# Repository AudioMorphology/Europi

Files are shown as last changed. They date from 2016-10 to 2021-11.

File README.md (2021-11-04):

# Europi

## Overview

The Europi is a 16hp Eurorack format sequencer powered by the Raspberry Pi single board computer. It is a digital sequencer that outputs Control Voltages (CV), Modulation and Gate signals, and can be controlled by a variety of signal sources including its own internal clock, external clocks, rotary encoders, MIDI sources and the like.

Europi has been designed to be modular and expandable. The main Europi module, which interfaces directly with the Raspberry Pi has the following features:

* 320 x 240 pixel 16-bit colour touchscreen display
* Continuous rotary push-button encoder
* 4 x tactile 'soft' buttons
* 2 x 1 v/Oct CV output (16-Bit resolution over a 10 volt range)
* 2 x Modulation outputs (16-Bit resolution over a 10 volt range)
* 2 x Gate ouputs (+5 volt leading-edge triggered)
* Clock Out
* Clock In
* Step 1 Out
* Reset In
* Hold In

The primary Europi module interfaces with a number of secondary modules.

The 6hp Europi Minion extends the output capabilities of the Europi by providing an additional 4 x CV and 4 x Gate outputs. Up to 8 Minions can be daisy-chained together so that, including the main Europi module, a complete system can support 34 x CV and 34 x Gate outputs.

The Europi MIDI Minion adds MIDI In, Out and Thru capability and can be used as a means of note entry, as a Clock source and also as a MIDI output. Up to 8 MIDI Minions can be connected to a Europi.

The intention is that, being open sourced, the initial hardware platform could be extended to include support for additional modules, control surfaces and such like, either by using the existing I2C bus that links the Europi to the Minions, or leveraging the USB capabilities of the Raspberry Pi.

## Open Source Hardware Certification

Europi Hardware is certified under the Open Source Hardware Certification Program. Certification Number UK000002

## Interfaces

The Europi is not an analogue sequencer, it is a digital sequencer that outputs analogue CV, Mod and Gate signals. Due to its digital nature the CV outputs are not infinitely variable, but are converted from digital to analogue using 16-Bit Digital to Analogue Converters  (DACs). This gives a resolution of around 6,000 discrete steps per octave over a 10 volt range, ie 500 per semitone. So, whilst the CV outputs are not continuously variable as in a true Analogue sequencer, the resolution is sufficiently high such that the difference isn't discernable in the vast majority of applications.

The output of the DACs have a full-scale output range of 0 to approx 5 volts. In reality, due to manufacturing tolerances, these outputs rarely reach a true zero and often have a minimum achievable output of around 20mv, so the DAC outputs are buffered via Op Amps that are biased with a slight negative voltage, and have an amplification factor of around 2.5 thus a true zero and full-scale 10v output can be set in software, which removes the need for complex and fiddly trimmer potentiometers.

The resistors biasing this output buffer circuit could be selected so that the output swings between, say +/-5v instead of the usual 0-10v, which would then be suitable for use as an audio output (via suitable drivers).

The CV and Gate outputs are connected to the Raspberry Pi using the main user Inter-Integrated Circuit (I2C) bus. The Raspberry Pi actually has two I2C busses, though the first (I2C-0) is generally reserved for querying 'hats' - add-on boards that sit on top of the Pi. The I2C bus is the slower of the Pi's two busses, but is the more flexible and extensible of the two. The faster SPI bus is used for the LCD display and its associated touchscreen interface. 

It is the I2C bus that is used to daisy-chain the various Minions to the main Europi. The I2C Bus is driven at 400KHz

The soft buttons, push-button rotary encoder, and external clock and reset inputs are connected to GPIO pins of the Raspberry Pi via suitable interface circuitry which provides over- and reverse-voltage protection.

Future expansion plans include a CV & Gate Input Minion for driving the Europi from External CV/Gate sources, a gesture-based controller, and a USB & HDMI Minion that connects the Raspberry Pi's USB output to a 2-Port Powered USB Hub, and brings the HDMI output through to a Eurorack panel. The latter is intended to make it simpler to pogram the Europi in situ, and opens the possibility for the connection of other control surfaces via USB.  

## Language and environment

Europi is written in C as it is fairly efficient and links directly with the PIGPIO library (see below). System and operational states are held in global variables. Opinions are divided over the use of global variables in C, though our view is that in a monolithic application such as this, global variables are both quick & efficient (less stack overheads) and simple to understand.

The GUI has been developed using Raylib (http://www.raylib.com), a free Open Source graphics library.

Touchscreen Input is interpreted by RayLib and mapped to Mouse Movements using the ts_uinput daemon, part of TSLIB.

## Principle of operation

Europi makes extensive use of the excellent PIGPIO library (https://github.com/joan2937/pigpio), in particular the I2C functions, PWM functions, and alert functions.

The main Internal clock is generated by establishing a PWM output on GPIO pin 18 (physical pin 12) against which a Callback function is registered. This callback function is therefore called each time the PWM output changes state. An internal counter divides this clock by 96 to give an internal resolution of 96 pulses per quarter note PPQN.

Due to the nature of the PIGPIO library, the PWM frequency can only be set to an integer number of cycles per second (Hz) and given the internal 96PPQN division, a range of typical BPM frequencies can be obtained using the following formula: BPM = (PWM/48)/60. So, for example, a PWM frequency of 200Hz will yield a corresponding BPM of 250 201Hz will yield 251.25 Etc. Obviously therefore, some BPM values cannot be realised using the internal clock due to this integer Hz limitation.

Using the external clock is a different matter as, presumably, an external oscillator can be set to any fractional frequency. The external clock is treated similarly to the internal clock - an alert function is registered against the GPIO pin to which it is applied (GPIO pin 12 Physical pin 32) and this is therefore called each time the external clock changes state. 

The MIDI Minion can alo be used as a clock source at the normal speed of 24 PPQN. 

Within the main body of the code, various control flags and counters are used to record the current operational state, internal vs external clock etc.

The main sequencer object is held in a single global structure called, understandably enough, Europi. Yes, this structure is inefficient. Yes, it would have saved space to malloc structures on the fly at startup, but  statically-defined structure such as this is easy to understand, and memory is not particularly at a premium in the Raspberry Pi.

The GUI has been developed using the Raylib graphics library (http://www.raylib.com). This was originally developed for games programming, but its 2D and text-handling elements are ideally suited to simple GUI development.

Although the Raspberry Pi can be configured to expose a TFT screen as a secondary framebuffer, it doesn't support hardware graphics acceleration when writing to it. I therefore chose to use Raylib to write to the default framebuffer /dev/fb0 and to use the free open source utility raspbi2fb (https://github.com/AndrewFromMelbourne/raspi2fb) to mirror /dev/fb0 to /dev/fb1 as this actually gives better graphic performance than writing directly to /dev/fb1

## Setup and Configuration

As always with Eurorack modules, care must be taken when attaching the module to a Eurorack PSU. We have included reverse-protection diodes to protect against inadvertent reversal of the supply connector, and also +12v and -12v marks are included on the silk screen to try and prevent errors. We have adopted the Doepfer 'standard' keyed shrouded header type of connector to also minimise potential errors.

Up to 8 Minions can be daisy-chained to a single Europi. There are two 6-way Minion connection headers on the main Europi board, one each side to make it easier to place the Minions to the left or right (or both) of the main Europi module. Minions can be daisy-chained in any order, the only stipulation being that each must be given a unique address on the I2C bus. Failure to do so will lead to unpredictable results.

The minion header mirrors the first 8 pins of the Raspberry Pi, so Minions can be connected using straight-through 8-way ribbon cables. Care must be taken to make sure Pin 1 is connected to Pin 1 etc.

As the Minion header mirrors the first 8 pins of the Raspberry Pi header, Minions can be connected directly to a Raspberry Pi without the need to include a Europi module, though obviously all of the functionality of the Europi would be missing from such a configuration (touchscreen LCD, rotary encoder etc) though it does represent a cheaper and simpler entry route into the realm of the Europi.

The Minion address is set using a 3-way DIP switch, using standard binary addressing: 000, 001, 010 .... 111 The address is read by the Minion when power is applied, so a Minion's address should never be changed whilst power is connected.

The MIDI Minion uses 2 separate jumpers to set one of 4 possible addresses, so 4 MIDI Minions can be connected to a Europi.

During startup, the Europi will scan the I2C bus looking for attached Minions, and will assign blocks of 4 Tracks to each Minion as it finds them. I2C address scanning starts from 000 so the Minion with the lowest address will be found first, and the highest last. Minion addresses do not have to be consecutive, just unique.

For ease of use, it would seem to make sense to assign Minion addresses in ascending order from left to right, though it's entirely up to you. During startup, the Europi will briefly flash all the Gate LEDs in the order it found them, which provides a useful indicator as to whether all Minions are in the correct order.

The second stage of the configuration is to set the Zero and Full scale levels for each CV output (both Europi and Minions). This only ever needs to be carried out once, or if the number or order of Minions is changed.

## Pi Configuration and Build Notes

These have been moved to the Wiki

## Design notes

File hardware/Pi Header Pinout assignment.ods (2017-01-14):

Europi – Pi Header pin assignments & function
Function | GPIO | Header Pin |  | GPIO | Function | Key
3v3+ | 3v3 | 1 | 2 | +5v | +5v |  | +5v
I2C1 SDA | I2C1 SDA | 3 | 4 | +5v | +5v |  | 3v3
I2C1 SCL | I2C1 SCL | 5 | 6 | GND | GND |  | GND
Enc A | GPIO 4 | 7 | 8 | GPIO 14 | Enc B |  | Input
GND | GND | 9 | 10 | GPIO 15 | Enc Button |  | Output
Touch Interrupt | GPIO 17 | 11 | 12 | GPIO 18 | System Clock |  | SPI Bus
TFT Reset | GPIO 27 | 13 | 14 | GND | GND |  | I2C Bus
TFT DS | GPIO 22 | 15 | 16 | GPIO 23
3v3+ | 3v3 | 17 | 18 | GPIO 24
SPI Input | SPI MOSI | 19 | 20 | GND | GND
SPI Output | SPI MOSO | 21 | 22 | GPIO 25
SPI Clock | SPI CLK | 23 | 24 | SPI CE0 | LCD Chip Select
GND | GND | 25 | 26 | SPI CE1 | Touch Panel Chip Select
I2C0 SDA | I2C0 SDA | 27 | 28 | I2C0 SCL | I2C0 SCL
Button 1 | GPIO 5 | 29 | 30 | GND | GND
Button 2 | GPIO 6 | 31 | 32 | GPIO 12 | CLK In
Button 3 | GPIO 13 | 33 | 34 | GND | GND
Button 4 | GPIO 19 | 35 | 36 | GPIO 16 | Reset In
Run/Stop | GPIO 26 | 37 | 38 | GPIO 20 | Int / Ext
GND | GND | 39 | 40 | GPIO 21 | Poss Button 5??

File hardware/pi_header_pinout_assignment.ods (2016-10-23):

Europi – Pi Header pin assignments & function
Function | GPIO | Header Pin |  | GPIO | Function | Key
3v3+ | 3v3 | 1 | 2 | +5v | +5v |  | +5v
I2C SPA | I2C SPA | 3 | 4 | +5v | +5v |  | 3v3
I2C SCL | I2C SCL | 5 | 6 | GND | GND |  | GND
Enc A | GPIO 4 | 7 | 8 | GPIO 14 | Enc B |  | Input
GND | GND | 9 | 10 | GPIO 15 | Enc Button |  | Output
Touch Interrupt | GPIO 17 | 11 | 12 | GPIO 18 | System Clock |  | SPI Bus
TFT Reset | GPIO 27 | 13 | 14 | GND | GND |  | I2C Bus
TFT DS | GPIO 22 | 15 | 16 | GPIO 23 | n/c |  | Reserved (Pi Hat EEPROM)
3v3+ | 3v3 | 17 | 18 | GPIO 24 | n/c |  | Not Connected
SPI Input | SPI MOSI | 19 | 20 | GND | GND
SPI Output | SPI MOSO | 21 | 22 | GPIO 25 | n/c
SPI Clock | SPI CLK | 23 | 24 | SPI CE0 | LCD Chip Select
GND | GND | 25 | 26 | SPI CE1 | Touch Panel Chip Select
n/c | x | 27 | 28 | x | n/c
Button 1 | GPIO 5 | 29 | 30 | GND | GND
Button 2 | GPIO 6 | 31 | 32 | GPIO 12 | CLK In
Button 3 | GPIO 13 | 33 | 34 | GND | GND
Button 4 | GPIO 19 | 35 | 36 | GPIO 16 | Reset In
Run/Stop | GPIO 26 | 37 | 38 | GPIO 20 | Int / Ext
GND | GND | 39 | 40 | GPIO 21 | n/c

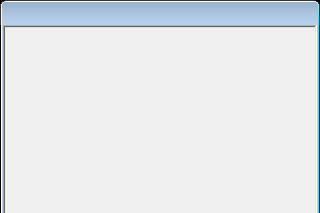
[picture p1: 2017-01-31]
resources/images/dialog.png

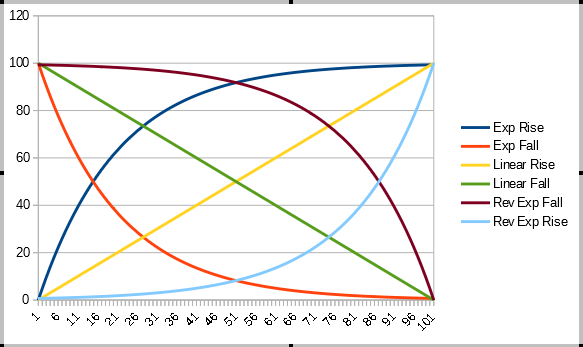
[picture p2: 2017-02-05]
resources/images/slew_profiles.png

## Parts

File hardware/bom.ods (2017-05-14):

Europi & Minion Bill Of Materials
Farnell # | Mouser # | Mfct Part # | Sort | Value | Type | Hole / Package | Europi | Minion | MIDI Minion | Approx Price (£) | Notes
9342400 |  | MF12 1K | 1 | 1k | 125mW 1% through-hole | 5mm | 6 | 4 |  | 0.0556 | Min Qty 5+
9342834 |  | MF12 2K2 | 1 | 2k2 | 125mW 1% through-hole | 5mm | 2 | 4 |  | 0.0526 | Min Qty 5+
9342419 |  | MF12 10K | 1 | 10k | 125mW 1% through-hole | 5mm | 8 | 11 |  | 0.0522 | Min Qty 5
9342826 |  | MF12 220R | 1 | 220R | 125mW 1% through-hole | 5mm | 6 | 8 |  | 0.53 | Sold in multiples of 50
9343245 |  | MF12 470R | 1 | 470R | 125mW 1% through-hole | 5mm | 4 | 4 |  | 0.53 | Sold in multiples of 50
9342800 |  | MF12 200K | 1 | 200k | 125mW 1% through-hole | 5mm | 2 | 4 |  | 0.53 | Sold in multiples of 50
9342850 |  | MF12 220K | 1 | 220k | 125mW 1% through-hole | 5mm |  | 4 |  | 0.53 | Sold in multiples of 50
1700284 |  | MCRE000080 | 1 | 3.9M | 125mW 5% through-hole | 5mm | 2 | 0 |  | 0.0424 | Min Qty 5
2309024 |  | MC0805Y103M500A5.08MM | 2 | 10nF (0.01uF) | Radial Lead ceramic capacitor | 5.08mm | 5 | 7 |  | 0.0934
1216440 |  | MCRR50104X7RK0050 | 2 | 100nF (0.1uF) | Radial Lead ceramic capacitor | 5.08mm | 2 | 2 |  | 0.157 | Min Qty 5
2309021 | 810-FK24X7R1H334K | MC0805B334K500A5.08MM | 2 | 330nF (0.33uF) | Radial Lead ceramic capacitor | 5.08mm | 1 | 1 |  | 0.21
8766754 | 667-EEA-FC1E100 | ECA1EAK100X | 2 | 10uF | Electrolytic 4x7mm 25v | 2.0mm | 3 | 3 |  | 0.0471 | Min Qty 5
9565124 | 512-1N4148 | 1N4148 | 3 | 1N4148 | High speed small signal diode | DO35-7 / 7mm | 8 | 4 |  | 0.0143 | Min Qty 10+
1017589 | 863-1N5819G | 1N5819 | 3 | 1N5819 | Schottky Diode 1A | DO41-7.6 / 7.6mm | 2 | 2 |  | 0.214 | Min Qty 5+
2296047 | 512-LM7805ACT | LM7805ACT | 4 | LM7805 | 5v Regulator | TO-220 | 1 | 1 |  | 0.463 | These are 5v 1A.
 | 511-LD1117S33 | LD1117S33TR | 4 | LD1117 | 3v3 Regulator | SOT-223 | 0 | 0 | 1 | 0.35
1648707 | 595-OPA4130UA | OPA4130UA | 4 | OPA4130 | Quad Op Amp | SOIC-14 | 0 | 1 |  | 5.57
1459554 | 595-OPA2130UA | OPA2130UA | 4 | OPA2130 | Dual Op Amp | SOIC-8 | 1 | 0 |  | 4.04
1206884 | 595-DAC8574IPW | DAC8574IPWG4 | 4 | DAC8574 | Quad 16-Bit DAC | TSSOP-16 | 1 | 1 |  | 13.38
9845330 | 512-BSS138 | BSS138 | 4 | BSS138 | N-Channel MOSFET | SOT-23 | 2 | 2 |  | 0.096 | Min Qty 10+
1332086 |  | MCP23008-E/SO | 4 | MCP23008 | 8-Bit i2c GPIO Extender | SOIC-18 | 0 | 1 |  | 0.818
2101302 |  | PCF8574AT | 4 | PCF8574A | 8-Bit i2c GPIO Extender | SOIC-16 | 1 | 0 |  | 0.765 | Note: 8574A NOT 8574!! This is because it's on a different i2c address that doesn't conflict with MCP23008
 |  | 74HCT125D | 4 |  |  |  |  |  |  |  | Note: MUST be 74HCT not 74HC (ie must work with TTL not CMOS levels)
2402409 |  | 430186130716 | 6 | Momentary | Tall tactile Switch | 4-Pin DIP 7.62x10.16 | 4 | 0 |  | 0.468 | Shaft needs to be >7mm long
2292959 |  | A101CYCQ04 | 6 | SPDT on-on | On-on toggle switch | 4.76mm (3/16”) | 2 | 0 |  | 1.96
2474844 |  | PEC11R-4215F-S0024 | 6 | 2-Channel | 24-Pulse Rotary Encoder | 15mm Shaft length | 1 | 0 |  | 1.31
9473041 |  | 2MS1T1B5M2RE | 6 | On-on Toggle | Through-hole SPDT switch | 6mm | 2 | 0 |  | 1.31
1523985 |  | MCEI-03 | 7 | 3 Circuit Switch | SPST 3 Circuit DIP Switch | 2.54 pitch x 7.62mm | 0 | 1 |  | 0.459
1142502 |  | L-934GD | 3 | Green | 3mm LED | T1 2.54 pitch | 4 | 4 | 2 | 0.082 | Min Qty 5
 |  | PJ301M-12 | 7 | 3.5mm jack Socket | Thonkiconn | 3.5mm | 8 | 8 |  | 0.39 | Buy from Thonk
 |  |  | 7 | Nuts | Hex nuts for Thonkiconn sockets | m6 | 8 | 8 |  | 1.5 | Bag of 50
 | 490-SDS-50J | SDS-50J | 7 | 5-Pin 180 deg | PCB monted right-angle MIDI DIN |  | 0 | 0 | 3 | 0.82 | The ones from Mouser have the mounting holes, which are preferred
1022253 |  | M20-9990546 | 5 |  | 5-Pin DIL Male Header |  | 0 | 1 |  | 0.089 | Min Qty 10+
1593461 |  | 2212S-05SG-85 | 5 |  | 5-Pin DIL Female Header |  | 0 | 1 |  | 0.599 | Min Qty 10+
1022256 |  | M20-9990845 | 5 |  | 8-Pin DIL Male Header |  | 3 | 1 |  | 0.156 | Min Qty 10+
3419101 |  | 215297-8 | 5 |  | 8-Pin DIL Female Header |  | 3 | 0 |  |  | Note: Europi ones need to be low-ish profile (AMP from TE Connectivity from Farnell looks OK)
1593463 |  | 2212S-08SG-85 | 5 |  | 8-Pin DIL Female Header |  | 0 | 1 |  | 0.721 | Needs to match the height of the 5-Pin ones.
2215302 |  | T821106A1S100CEU | 5 |  | 6-Pin Male Shrouded Header |  | 2 | 2 | 2 | 0.47 | each
1392408 |  | 70246-1044 | 5 |  | 10-Pin Male Shrouded Header |  | 1 | 1 |  | 0.782 | Min Qty 5+
 |  |  | 5 |  | 26-Pin Male Header |  | 1 | 0 | 1 |  | For connecting the TFT LCD Screen – 2 x Rows of single pins will do.
2396214 |  | 10-98-7402 | 5 |  | 40-Pin male Header |  | 1 | 0 |  | 2.19 | For Raspberry Pi Zero, or Ribbon from Pi
 |  |  | 8 |  | Rotary encoder knob |  | 1 | 0 |  | 4.99 | For 5. Bought from led-essential on eBay
 |  |  | 8 |  | Eurorack power cable |  | 1 | 1 |  |  | 16pin to 10pin ribbon
 |  |  | 8 |  | Minion link cable |  | 0 | 1 |  |  | 6pin to 6pin ribbon

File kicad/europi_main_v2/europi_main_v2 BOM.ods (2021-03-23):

Id | Designator | Package | Quantity | Designation | Supplier and ref
1 | C1,C2,C5 | CP_Radial_D5.0mm_P2.00mm | 3 | 10uF
2 | C11,C8,C10,C12,C13,C6,C9 | C_0805_2012Metric_Pad1.15x1.40mm_HandSolder | 7 | 10n
3 | D1,D2 | D_DO-41_SOD81_P10.16mm_Horizontal | 2 | 1N5819
4 | D3,D4,D5,D6 | LED_D3.0mm | 4 | LED
5 | D7,D8,D9,D10,D11,D12,D13,D14,D15,D16 | D_SOD-123 | 10 | 1N4148
6 | Eurorack1 | IDC_Header_Straight_10pins | 1 | CONN_02X05
7 | J1,J2,J3,J4,J5,J6,J7,J8,J16,J14,J13 | Thonkiconn | 11 | Thonkiconn
8 | Pi1 | Raspberry_Pi_Zero_Socketed | 1 | Raspberry Pi
9 | Q1,Q2 | SOT-23 | 2 | BSS138
10 | R1,R2,R3,R4,R5,R6,R8,R12 | R_0805_2012Metric_Pad1.15x1.40mm_HandSolder | 8 | 10k
11 | R17,R18,R19,R20,R27,R28,R40,R39 | R_0805_2012Metric_Pad1.15x1.40mm_HandSolder | 8 | 220R
12 | R21,R22,R23,R24 | R_0805_2012Metric_Pad1.15x1.40mm_HandSolder | 4 | 470R
13 | R25,R26,R41 | R_0805_2012Metric_Pad1.15x1.40mm_HandSolder | 3 | 3m6
14 | R29,R30,R42 | R_0805_2012Metric_Pad1.15x1.40mm_HandSolder | 3 | 1K
15 | SW1 | SPDT_Switch | 1 | SW_SPDT
16 | SW3 | Rotary_encoder_sw_concise | 1 | RotaryEncoder_Switch
17 | SW4 | SW_PUSH_6mm | 1 | BTN_1
18 | SW5 | SW_PUSH_6mm | 1 | BTN_2
19 | SW6 | SW_PUSH_6mm | 1 | BTN_3
20 | SW7 | SW_PUSH_6mm | 1 | BTN_4
21 | PCF8574A1 | SOIC-16W_7.5x10.3mm_P1.27mm | 1 | PCF8574A
22 | , | AM_Logo | 2
23 |  | OSHW-Logo2_14.6x12mm_SilkScreen | 1
24 | R32,R31,R34,R33,R9,R10,R11,R7 | R_0805_2012Metric_Pad1.15x1.40mm_HandSolder | 8 | 1k
25 | R37,R36,R35,R38 | R_0805_2012Metric_Pad1.15x1.40mm_HandSolder | 4 | 2k2
26 | R14,R16,R15,R13 | R_0805_2012Metric_Pad1.15x1.40mm_HandSolder | 4 | 200k
27 | OPA4130 | SOIC-14_3.9x8.7mm_P1.27mm | 1 | OPA4134
28 | C4,C7 | tantalum_capacitor | 2 | 100n
29 | C3 | tantalum_capacitor | 1 | 330n
30 | LM7805 | TO-220-3_Vertical | 1 | LM7805_TO220
31 | J11,J9 | PinHeader_2x04_P2.54mm_Vertical | 2 | Conn_02x04_Odd_Even
32 | DAC8574 | TSSOP-16_4.4x5mm_P0.65mm | 1 | DAC8574
33 | P3,P4,P6,P7 | PinHeader_1x08_P2.54mm_Vertical | 4 | Conn_01x08
34 | J17,J19 | PinHeader_1x06_P2.54mm_Vertical | 2 | Conn_01x06
35 | J18,J20 | PinHeader_1x05_P2.54mm_Vertical | 2 | Conn_01x05
36 | J10 | MSP2402 | 1 | Conn_01x14

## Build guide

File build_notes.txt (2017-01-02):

Europi Install & Build instructions

Download, compile and install the PIGPIO library\	

edit /boot/config.txt and take the comment off the following line:
#dtparam=spi=on

add the following line to prevent the under-voltage warning being displayed if
the power voltage drops:
avoid_warnings=1

Note: If you change the 1 to a 2, then it will also prevent the Pi disabling Turbo mode
if the power drops (normal behaviour). i thought this a bit risky, as it might cause the 
pi to crash, hence why I stuck with the =1

Add the ads7846 touchscreen overlay:
 - Towards the end of /boot/config.txt add the following line:
 dtoverlay=ads7846,penirq=17,speed=1600000,xohms=100

The following line loads the fbtft driver manually, though note that later on in this doc
there is an explanation as to how to load the fbtft driver at boot time

sudo modprobe fbtft_device custom name=fb_iti9340 buswidth=8 speed=16000000 bgr=1 gpios=reset:27,dc:22 rotate=270

Also in /boot/config.txt if you add the following lines, it will force the raspberry Pi into native 
1280x960 graphics mode, which is the same aspect ration (4:3) as the 320x240 TFT display. Doing
this has certain advantages inasmuch as it is then possible, whilst deverloping under X11
to check the resulting display on the 320x240TFT display as it scales exactly:

framebuffer_width=1280
framebuffer_height=960
hdmi_group=2
hdmi_mode=32
hdmi_cvt 1280 960 60 1 0 0 0 

When you are ready to run headless with only the TFT display, use the following instead, which 
will set the Pi to native 320x240:
framebuffer_width=320
framebuffer_height=240
hdmi_group=2
hdmi_mode=87
hdmi_cvt 320 240 60 1 0 0 0 

The following two changes mean that you don't have to run the sudo modprobe line each time the pi boots:

>sudo nano /etc/modules-load.d/modules.conf

add the following 2 lines:

spi-bcm2835
fbtft_device

>sudo nano /etc/modprobe.d/fbtft.conf   (ie create this file, as it probably doesn't already exist)

add the following line:

options fbtft_device custom name=fb_ili9340 buswidth=8 speed=16000000 bgr=1 gpios=reset:27,dc:22 rotate=270

Note that the argument bgr=1 is only necessary to fix the situation where Red and Blue colours are swapped, which
it the case with the SpotPear TFT Screens.

To get europi to run automatically at startup, do the following: 

>sudo crontab -e

If it gives you a choice of editor, choose whichever you want (I use nano). Once you have made a choice, it'll open in that editor from then onwards

Add the following to the bottom of the crontab file:

@reboot /usr/bin/sudo /home/pi/projects/Europi/europi

SET The Touchscreen Device:
Depending on how many devices are connected to the SPI bus, the Touchscreen may appear as
device1, 2,  3 etc., to view the input devices:
>cat /proc/bus/input/devices

Mine looks like this:
I: Bus=0000 Vendor=0000 Product=0000 Version=0000
N: Name="ADS7846 Touchscreen"
P: Phys=spi0.1/input0
S: Sysfs=/devices/platform/soc/3f204000.spi/spi_master/spi0/spi0.1/input/input3
U: Uniq=
H: Handlers=mouse1 event3 
B: PROP=0
B: EV=b
B: KEY=400 0 0 0 0 0 0 0 0 0 0
B: ABS=1000003

That H: line shows that it is being handled by event3

Fri 24th June: I was adding stuff to get me to the stsage where I could use IOCTL to read touch events
I got the prog to compile OK, but it crashes with a SIGINT 11 (basically a memory violation) as it 
tries to query the device capabilities.

Sat 25th Jun: I removed all the touchscreen code I'd added, and decided instead to just try linking 
in the example C code from Mark Williams

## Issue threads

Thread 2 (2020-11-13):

Continue development?

Deftaudio, 2020-11-13:
Hi, just wondering if you continue developing of this project by adding more features or it's abandoned?

AudioMorphology, 2020-11-13:
Hi, I stopped development as I wasn't happy with the mechanical attachment of the Pi Zero or the computing power of the Pi Zero at that time. I also needed time (and money) to buy more Eurorack modules - a fully-populated EuroPi can drive 30+ CV and Gate outputs, so I needed more modules to control!

However, now that the Pi 4 Compute Module (CM4) has been released I plan to re-design the hardware to use the CM4, I have one on order and I expect it to arrive next week.

The form factor is much better for attaching to the rear of a Eurorack module.

I also realised that, for MIDI in, I really needed to bring an interrupt line from the MIDI Minion, because Polling for MIDI messages gave me lots of timing problems.

So, nothing has happened for a long time, but I hope to be able to start on a new version soon!

Richard

Deftaudio, 2020-11-13:
Hi Richard, this is great to hear. I've been thinking about Pi based design for quite few years. My idea was to use it mainly for MIDI processing within PD. So with that I can't use custom circuit to drive digital pins without actually writing a full MIDI driver stack. So, as I'm not experienced in that,  I've been thinking on the Teensy+Pi design. in the meantime, with all overhead of the polling mode, this is the approach for low jitter implementation, even consuming lot of Pi cycles.

Closed 2021-02-23.

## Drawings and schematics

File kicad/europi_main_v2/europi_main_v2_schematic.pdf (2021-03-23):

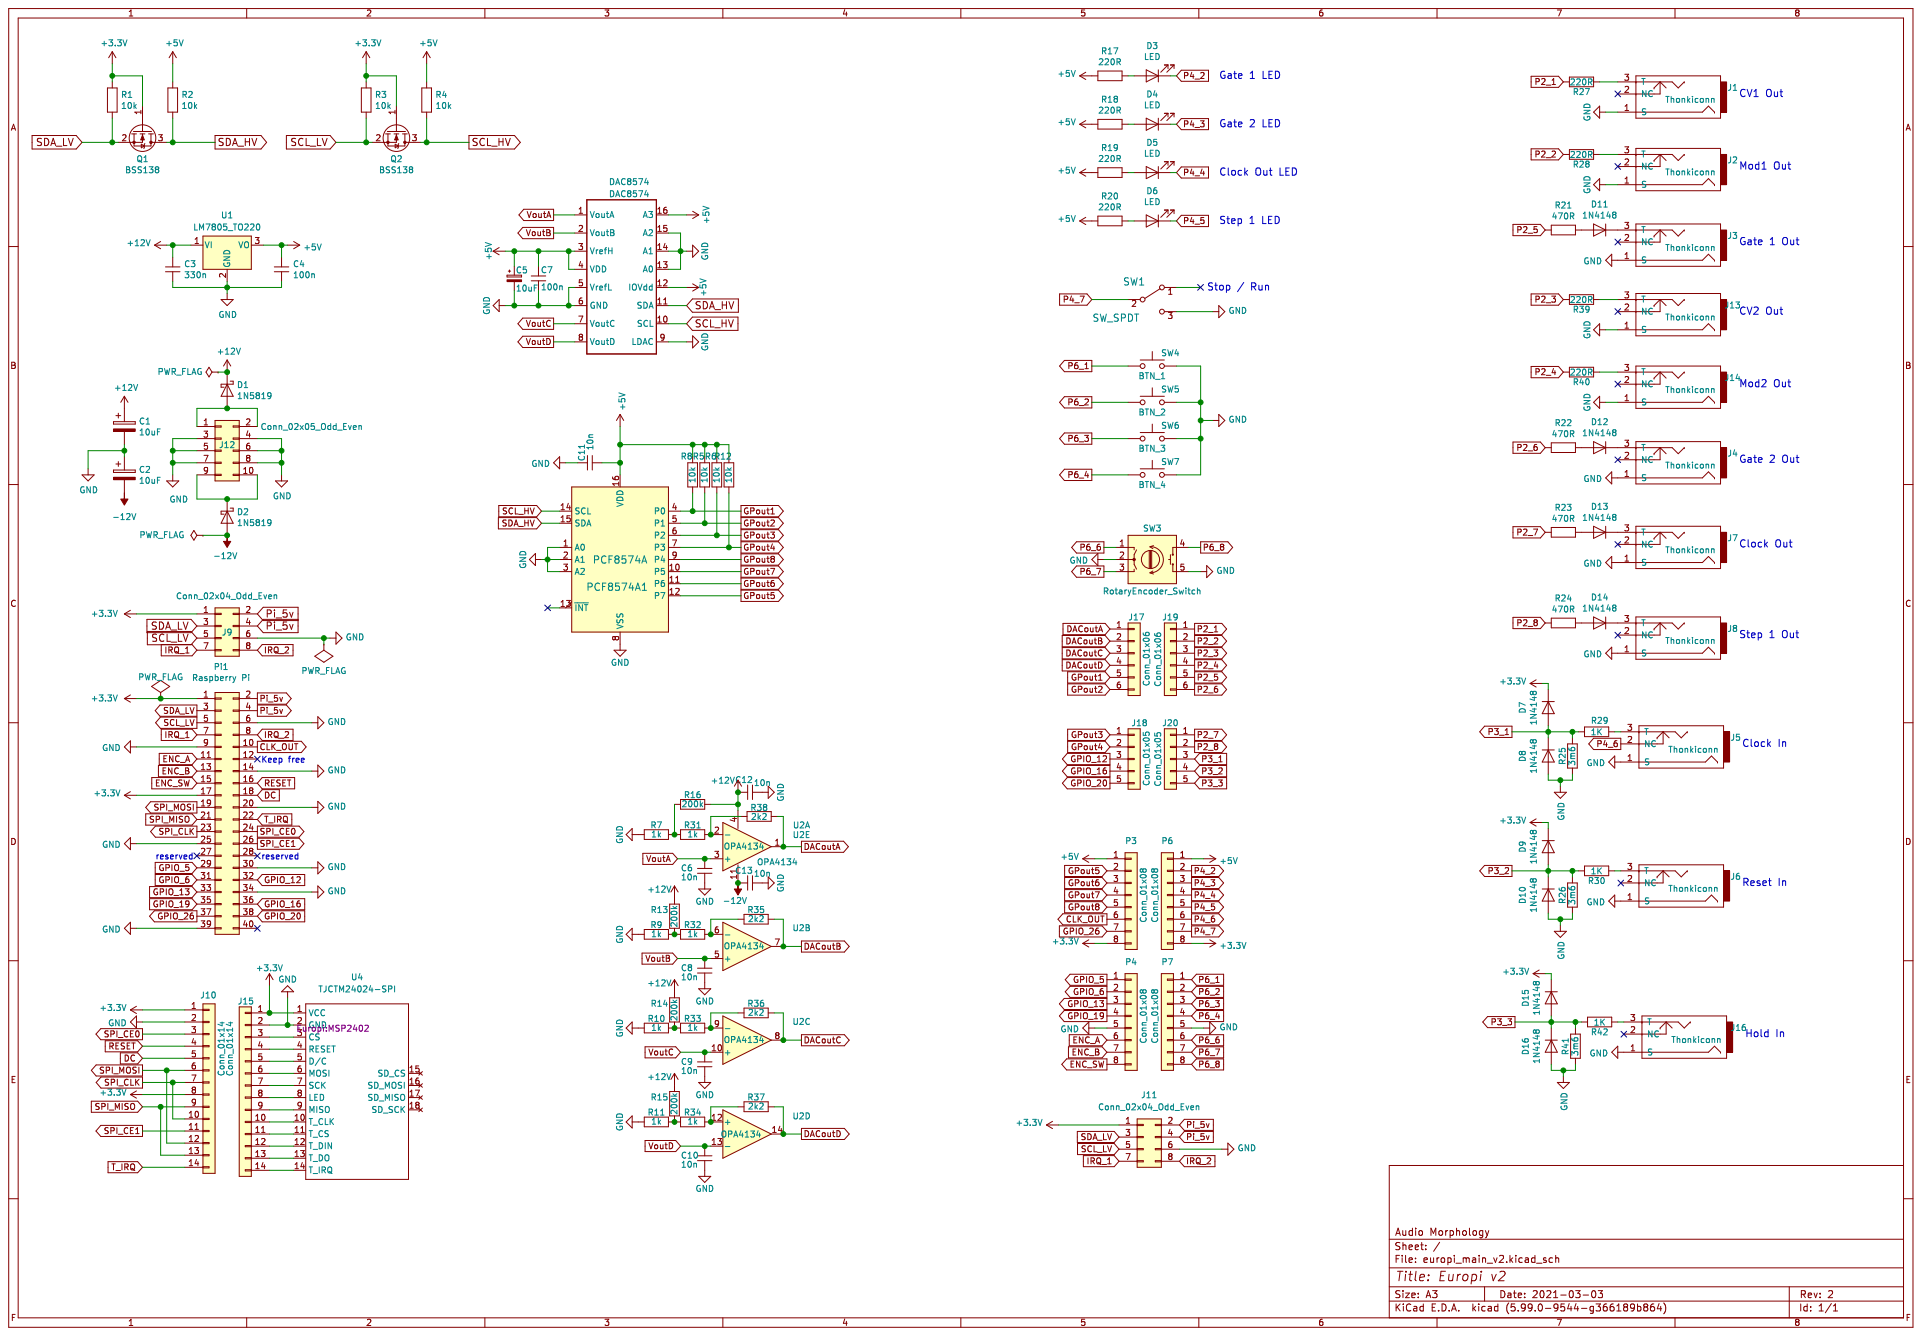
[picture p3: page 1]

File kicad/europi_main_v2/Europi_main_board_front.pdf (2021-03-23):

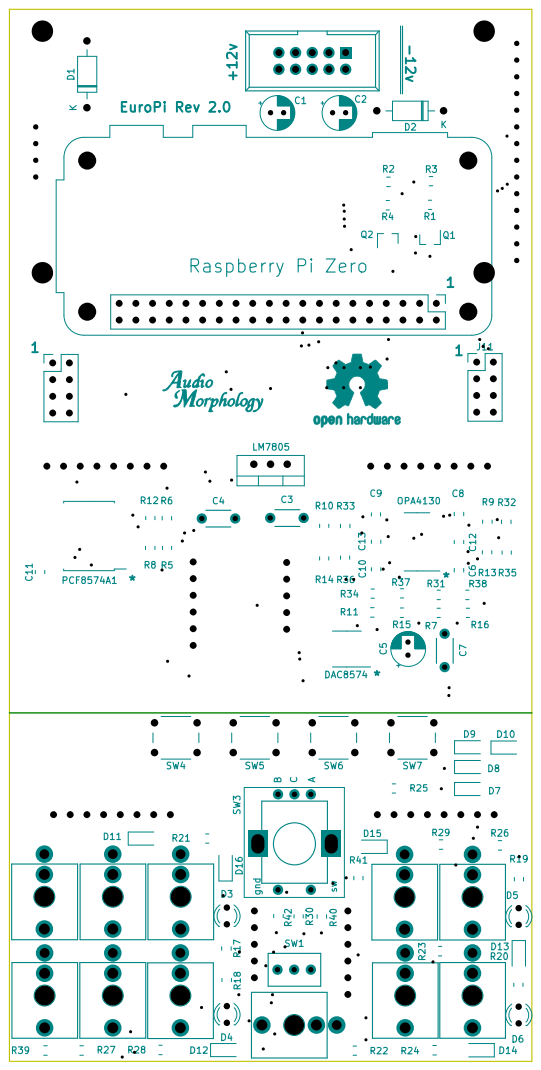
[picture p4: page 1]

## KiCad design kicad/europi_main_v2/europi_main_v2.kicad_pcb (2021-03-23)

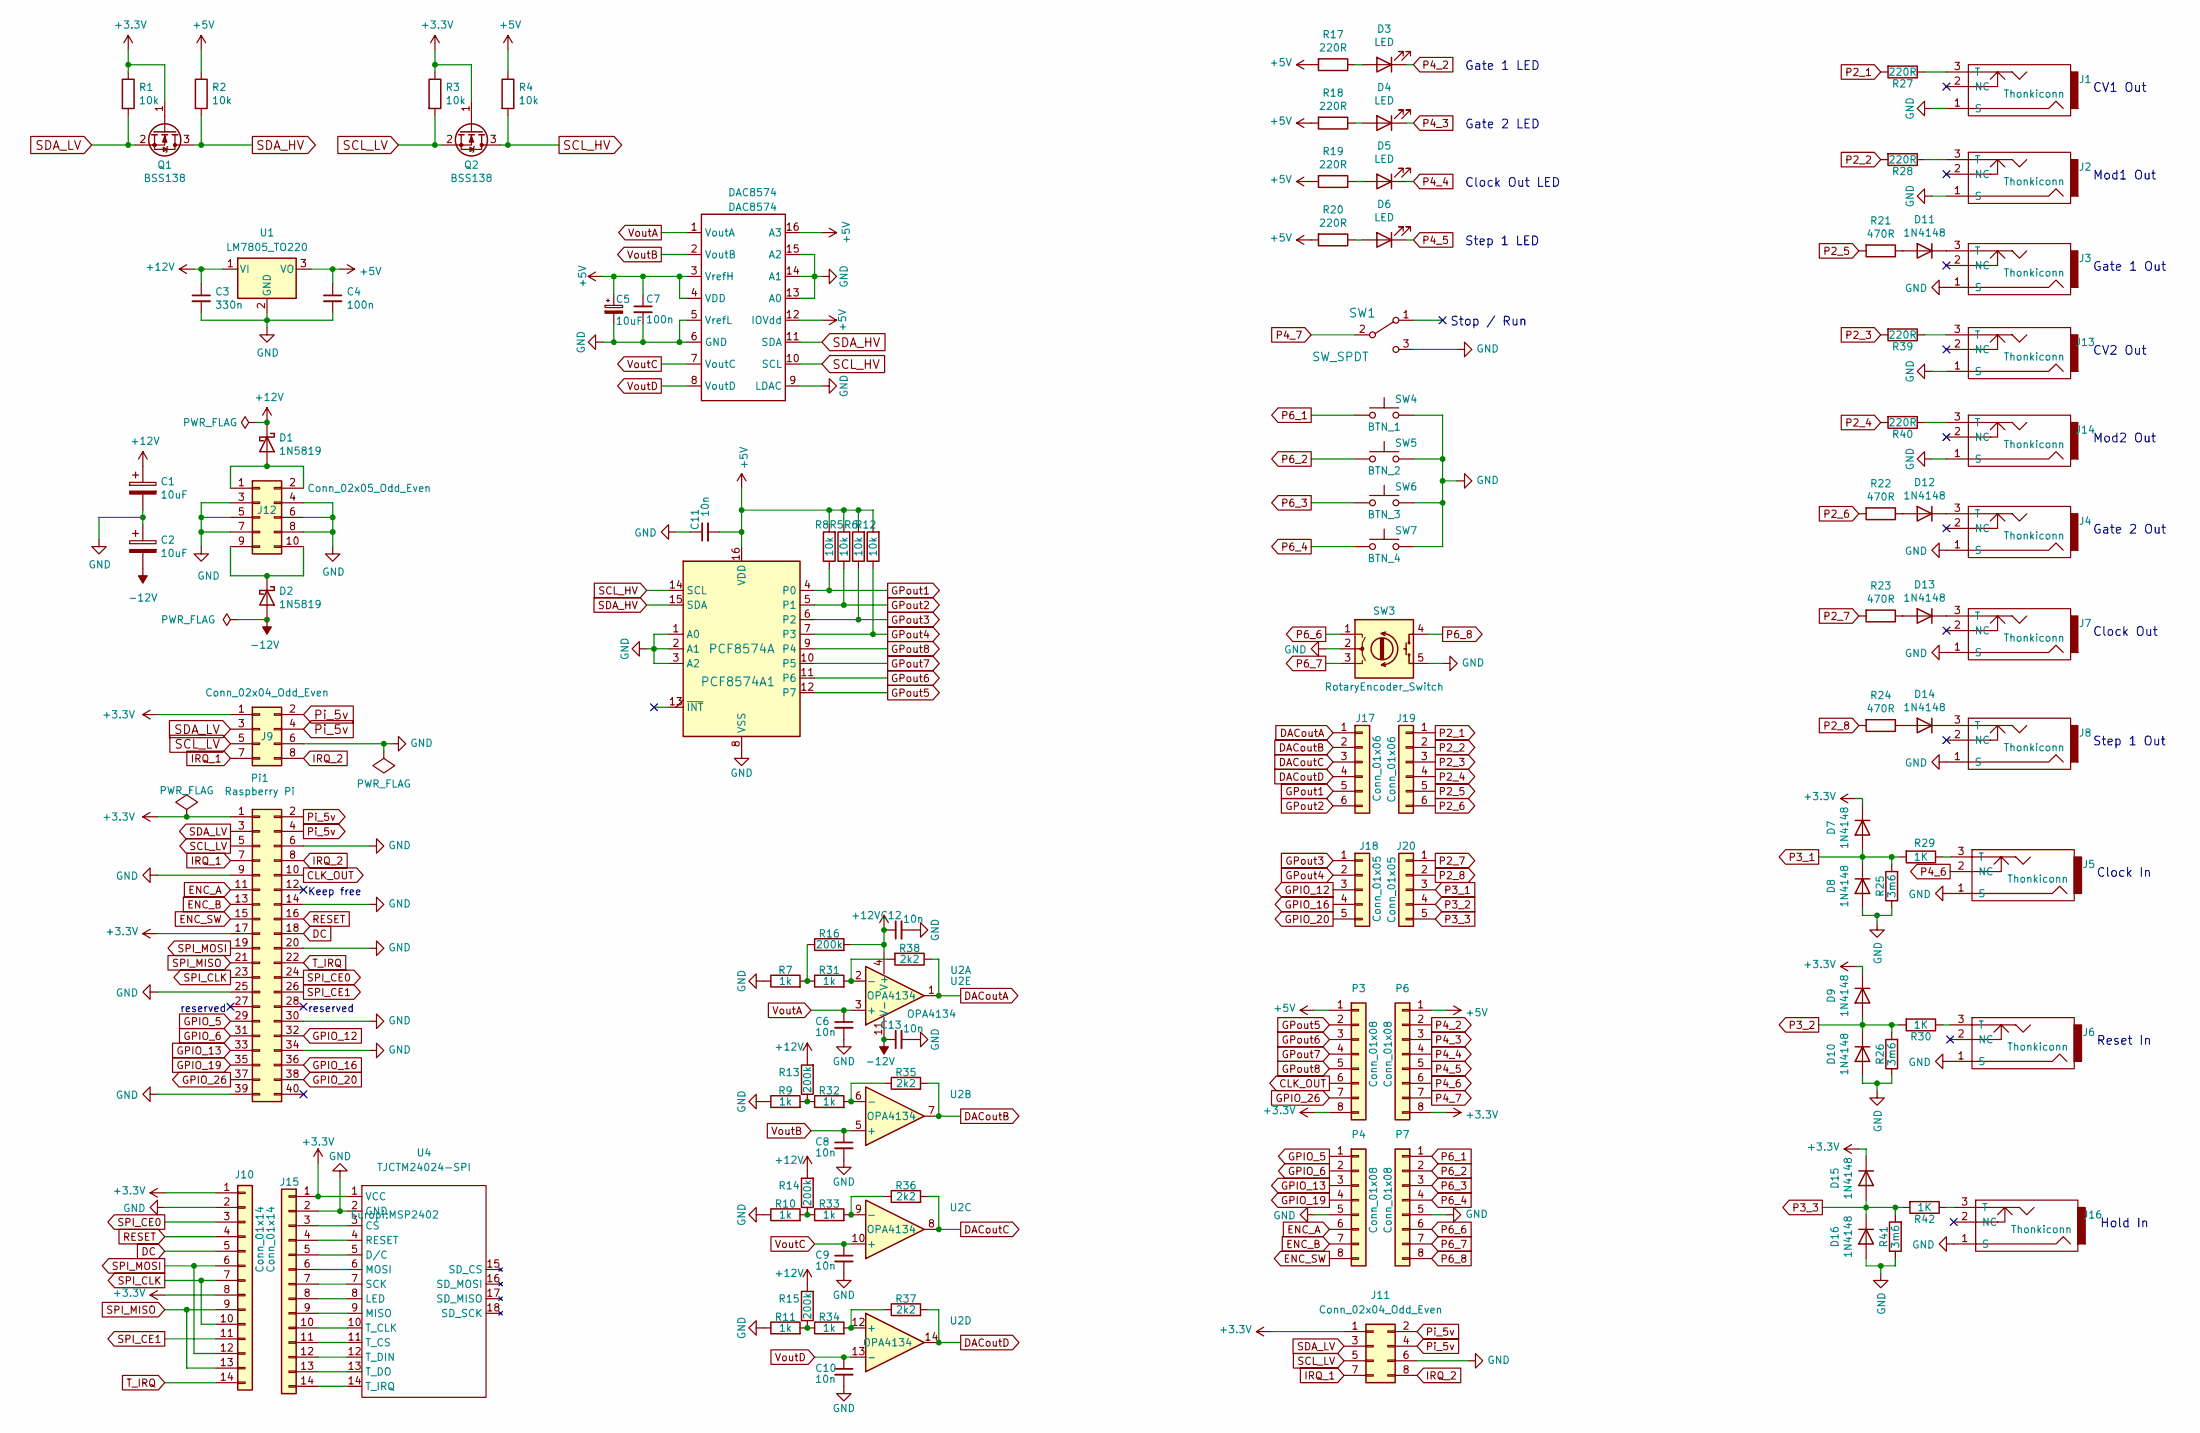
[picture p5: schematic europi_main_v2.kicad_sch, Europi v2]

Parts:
C1, C2, C5: 10uF; CP_Radial_D5.0mm_P2.00mm
C3: 330n; tantalum_capacitor
C4, C7: 100n; tantalum_capacitor
C6, C8, C9, C10, C11, C12, C13: 10n; C_0805_2012Metric_Pad1.15x1.40mm_HandSolder
D1, D2: 1N5819; D_DO-41_SOD81_P10.16mm_Horizontal
D3, D4, D5, D6: LED; LED_D3.0mm
D7, D8, D9, D10, D11, D12, D13, D14, D15, D16: 1N4148; D_SOD-123
DAC8574: DAC8574; TSSOP-16_4.4x5mm_P0.65mm
J1, J2, J3, J4, J5, J6, J7, J8, J13, J14, J16: Thonkiconn
J9, J11: Conn_02x04_Odd_Even; PinHeader_2x04_P2.54mm_Vertical
J10, J15: Conn_01x14; PinHeader_1x14_P2.54mm_Vertical
J12: Conn_02x05_Odd_Even; PinHeader_2x05_P2.54mm_Vertical
J17, J19: Conn_01x06; PinHeader_1x06_P2.54mm_Vertical
J18, J20: Conn_01x05; PinHeader_1x05_P2.54mm_Vertical
P3, P4, P6, P7: Conn_01x08; PinHeader_1x08_P2.54mm_Vertical
PCF8574A1: PCF8574A; SOIC-16W_7.5x10.3mm_P1.27mm
Pi1: Raspberry Pi; Raspberry_Pi_Zero_Socketed
Q1, Q2: BSS138; SOT-23
R1, R2, R3, R4, R5, R6, R8, R12: 10k; R_0805_2012Metric_Pad1.15x1.40mm_HandSolder
R7, R9, R10, R11, R31, R32, R33, R34: 1k; R_0805_2012Metric_Pad1.15x1.40mm_HandSolder
R13, R14, R15, R16: 200k; R_0805_2012Metric_Pad1.15x1.40mm_HandSolder
R17, R18, R19, R20, R27, R28, R39, R40: 220R; R_0805_2012Metric_Pad1.15x1.40mm_HandSolder
R21, R22, R23, R24: 470R; R_0805_2012Metric_Pad1.15x1.40mm_HandSolder
R25, R26, R41: 3m6; R_0805_2012Metric_Pad1.15x1.40mm_HandSolder
R29, R30, R42: 1K; R_0805_2012Metric_Pad1.15x1.40mm_HandSolder
R35, R36, R37, R38: 2k2; R_0805_2012Metric_Pad1.15x1.40mm_HandSolder
SW1: SW_SPDT; SPDT_Switch
SW3: RotaryEncoder_Switch; Rotary_encoder_sw_concise
SW4: BTN_1; SW_PUSH_6mm
SW5: BTN_2; SW_PUSH_6mm
SW6: BTN_3; SW_PUSH_6mm
SW7: BTN_4; SW_PUSH_6mm
U1: LM7805_TO220; TO-220-3_Vertical
U2: OPA4134; SOIC-14_3.9x8.7mm_P1.27mm
U4: TJCTM24024-SPI; MSP2402

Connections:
+3V3: D7.1 (K), D9.1 (K), D15.1 (K), J9.1, J10.1, J10.8, J11.1, J15.1, P3.8, P6.8, Pi1.1, Pi1.17, Q1.1 (G), Q2.1 (G), R1.1, R3.1, U4.1 (VCC)
+5V: C4.1, C5.1, C7.1, C11.2, DAC8574.3 (VrefH), DAC8574.4 (VDD), DAC8574.12 (IOVdd), DAC8574.16 (A3), P3.1, P6.1, PCF8574A1.16 (VDD), R2.1, R4.1, R5.2, R6.2, R8.2, R12.2, R17.2, R18.2, R19.2, R20.2, U1.3 (VO); also elsewhere on the board
+12V: C1.1, C3.1, C12.1, D1.1 (K), R13.2, R14.2, R15.2, R16.2, U1.1 (VI), U2.4 (V+); also elsewhere on the board
-12V: C2.2, C13.1, D2.2 (A), U2.11 (V-); also elsewhere on the board
CLK_OUT: P3.6, Pi1.10
DACoutA: J17.1, R38.1, U2.1; also elsewhere on the board
DACoutB: J17.2, R35.2, U2.7; also elsewhere on the board
DACoutC: J17.3, R36.2, U2.8; also elsewhere on the board
DACoutD: J17.4, R37.2, U2.14; also elsewhere on the board
DC: J10.5, Pi1.18
ENC_A: P4.6, Pi1.11
ENC_B: P4.7, Pi1.13
ENC_SW: P4.8, Pi1.15
GND: C1.2, C2.1, C3.2, C4.2, C5.2, C6.2, C7.2, C8.2, C9.2, C10.2, C11.1, C12.2, C13.2, D8.2 (A), D10.2 (A), D16.2 (A), DAC8574.5 (VrefL), DAC8574.6 (GND), DAC8574.9 (LDAC), DAC8574.13 (A0), DAC8574.14 (A1), DAC8574.15 (A2), J1.1 (S), J2.1 (S), J3.1 (S), J4.1 (S), J5.1 (S), J6.1 (S), J7.1 (S), J8.1 (S), J9.6, J10.2, J11.6, J12.3, J12.4, J12.5, J12.6, J12.7, J12.8, J13.1 (S), J14.1 (S), J15.2, J16.1 (S), P4.5, P7.5, PCF8574A1.1 (A0), PCF8574A1.2 (A1), PCF8574A1.3 (A2), PCF8574A1.8 (VSS), Pi1.6, Pi1.9, Pi1.14, Pi1.20, Pi1.25, Pi1.30, Pi1.34, Pi1.39, R7.1, R9.1, R10.1, R11.1, R25.1, R26.1, R41.1, SW1.3 (C), SW3.2 (C), SW3.5 (S2), SW4.2, SW5.2, SW6.2, SW7.2, U1.2 (GND), U4.2 (GND); also elsewhere on the board
GPIO_5: P4.1, Pi1.29
GPIO_6: P4.2, Pi1.31
GPIO_12: J18.3, Pi1.32
GPIO_13: P4.3, Pi1.33
GPIO_16: J18.4, Pi1.36
GPIO_19: P4.4, Pi1.35
GPIO_20: J18.5, Pi1.38
GPIO_26: P3.7, Pi1.37
GPout1: J17.5, PCF8574A1.4 (P0), R8.1
GPout2: J17.6, PCF8574A1.5 (P1), R5.1
GPout3: J18.1, PCF8574A1.6 (P2), R6.1
GPout4: J18.2, PCF8574A1.7 (P3), R12.1
GPout5: P3.2, PCF8574A1.12 (P7)
GPout6: P3.3, PCF8574A1.11 (P6)
GPout7: P3.4, PCF8574A1.10 (P5)
GPout8: P3.5, PCF8574A1.9 (P4)
IRQ_1: J9.7, J11.7, Pi1.7
IRQ_2: J9.8, J11.8, Pi1.8
unnamed 32: D1.2 (A), J12.1, J12.2; also elsewhere on the board
unnamed 33: D2.1 (K), J12.9, J12.10; also elsewhere on the board
unnamed: D3.2 (A), R17.1
unnamed: D4.2 (A), R18.1
unnamed: D5.2 (A), R19.1
unnamed: D6.2 (A), R20.1
unnamed: D11.1 (K), J3.3 (T)
unnamed: D11.2 (A), R21.1
unnamed: D12.1 (K), J4.3 (T)
unnamed: D12.2 (A), R22.1
unnamed: D13.1 (K), J7.3 (T)
unnamed: D13.2 (A), R23.1
unnamed: D14.1 (K), J8.3 (T)
unnamed: D14.2 (A), R24.1
unnamed: J1.3 (T), R27.1
unnamed: J2.3 (T), R28.1
unnamed: J5.3 (T), R29.1
unnamed: J6.3 (T), R30.1
unnamed: J13.3 (T), R39.1
unnamed: J14.3 (T), R40.1
unnamed: J15.3, U4.3 (CS)
unnamed: J15.4, U4.4 (RESET)
unnamed: J15.5, U4.5 (D/C)
unnamed: J15.6, U4.6 (MOSI)
unnamed: J15.7, U4.7 (SCK)
unnamed: J15.8, U4.8 (LED)
unnamed: J15.9, U4.9 (MISO)
unnamed: J15.10, U4.10 (T_CLK)
unnamed: J15.11, U4.11 (T_CS)
unnamed: J15.12, U4.12 (T_DIN)
unnamed: J15.13, U4.13 (T_DO)
unnamed: J15.14, U4.14 (T_IRQ)
unnamed: J16.3 (T), R42.1
unnamed: R10.2, R14.1, R33.1
unnamed: R11.2, R15.1, R34.1
unnamed: R9.2, R13.1, R32.1
unnamed: R7.2, R16.1, R31.1
unnamed 69: R31.2, R38.2, U2.2 (-); also elsewhere on the board
unnamed 70: R32.2, R35.1, U2.6 (-); also elsewhere on the board
unnamed 71: R33.2, R36.1, U2.9 (-); also elsewhere on the board
unnamed 72: R34.2, R37.1, U2.12 (+); also elsewhere on the board
P2_1: J19.1, R27.2
P2_2: J19.2, R28.2
P2_3: J19.3, R39.2
P2_4: J19.4, R40.2
P2_5: J19.5, R21.2
P2_6: J19.6, R22.2
P2_7: J20.1, R23.2
P2_8: J20.2, R24.2
P3_1: D7.2 (A), D8.1 (K), J20.3, R25.2, R29.2
P3_2: D9.2 (A), D10.1 (K), J20.4, R26.2, R30.2
P3_3: D15.2 (A), D16.1 (K), J20.5, R41.2, R42.2
P4_2: D3.1 (K), P6.2
P4_3: D4.1 (K), P6.3
P4_4: D5.1 (K), P6.4
P4_5: D6.1 (K), P6.5
P4_6: J5.2 (NC), P6.6
P4_7: P6.7, SW1.2 (B)
P6_1: P7.1, SW4.1
P6_2: P7.2, SW5.1
P6_3: P7.3, SW6.1
P6_4: P7.4, SW7.1
P6_6: P7.6, SW3.1 (A)
P6_7: P7.7, SW3.3 (B)
P6_8: P7.8, SW3.4 (S1)
Pi_5v: J9.2, J9.4, J11.2, J11.4, Pi1.2, Pi1.4
RESET: J10.4, Pi1.16
SCL_HV: DAC8574.10 (SCL), PCF8574A1.14 (SCL), Q2.3 (D), R4.2
SCL_LV: J9.5, J11.5, Pi1.5, Q2.2 (S), R3.2
SDA_HV: DAC8574.11 (SDA), PCF8574A1.15 (SDA), Q1.3 (D), R2.2
SDA_LV: J9.3, J11.3, Pi1.3, Q1.2 (S), R1.2
SPI_CE0: J10.3, Pi1.24
SPI_CE1: J10.11, Pi1.26
SPI_CLK: J10.7, J10.10, Pi1.23
SPI_MISO: J10.9, J10.13, Pi1.21
SPI_MOSI: J10.6, J10.12, Pi1.19
T_IRQ: J10.14, Pi1.22
VoutA: C6.1, DAC8574.1 (VoutA), U2.3 (+); also elsewhere on the board
VoutB: C8.1, DAC8574.2 (VoutB), U2.5 (+); also elsewhere on the board
VoutC: C9.1, DAC8574.7 (VoutC), U2.10 (+); also elsewhere on the board
VoutD: C10.1, DAC8574.8 (VoutD), U2.13 (-); also elsewhere on the board

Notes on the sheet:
reserved
Keep free
Stop / Run
Gate 1 LED
Gate 2 LED
Clock Out LED
Step 1 LED
CV1 Out
Mod1 Out
Gate 1 Out
CV2 Out
Mod2 Out
Gate 2 Out
Clock Out
Step 1 Out
Clock In
Reset In
Hold In

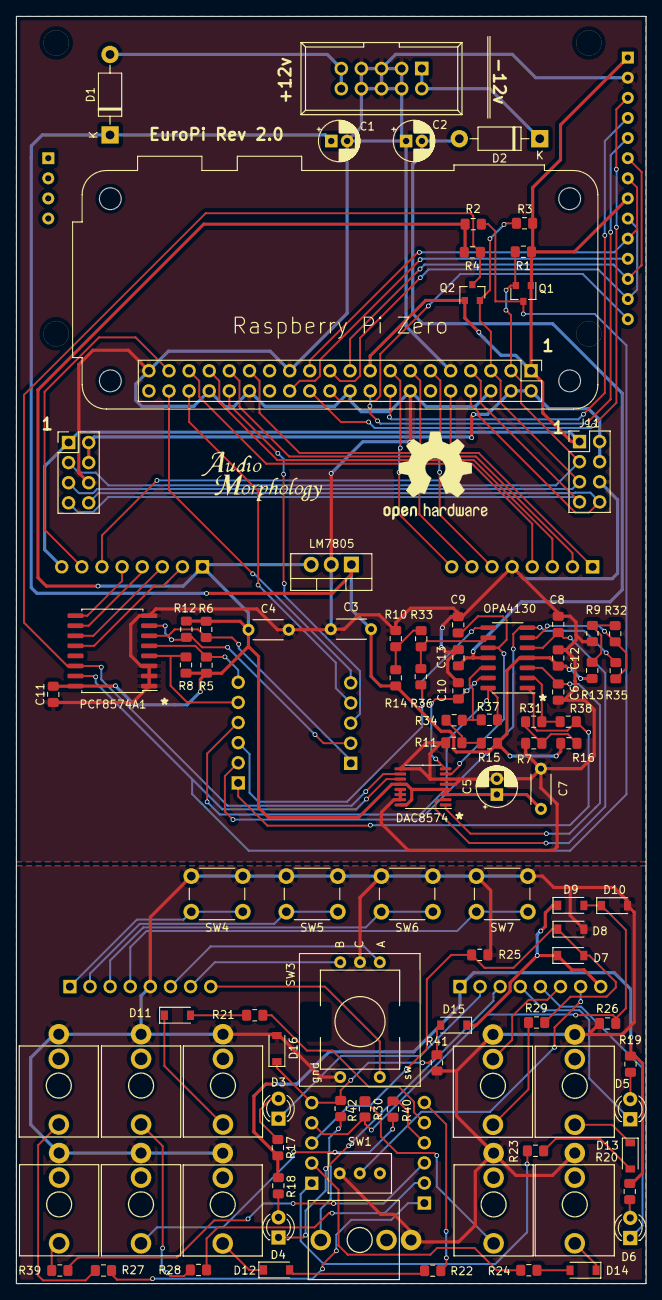
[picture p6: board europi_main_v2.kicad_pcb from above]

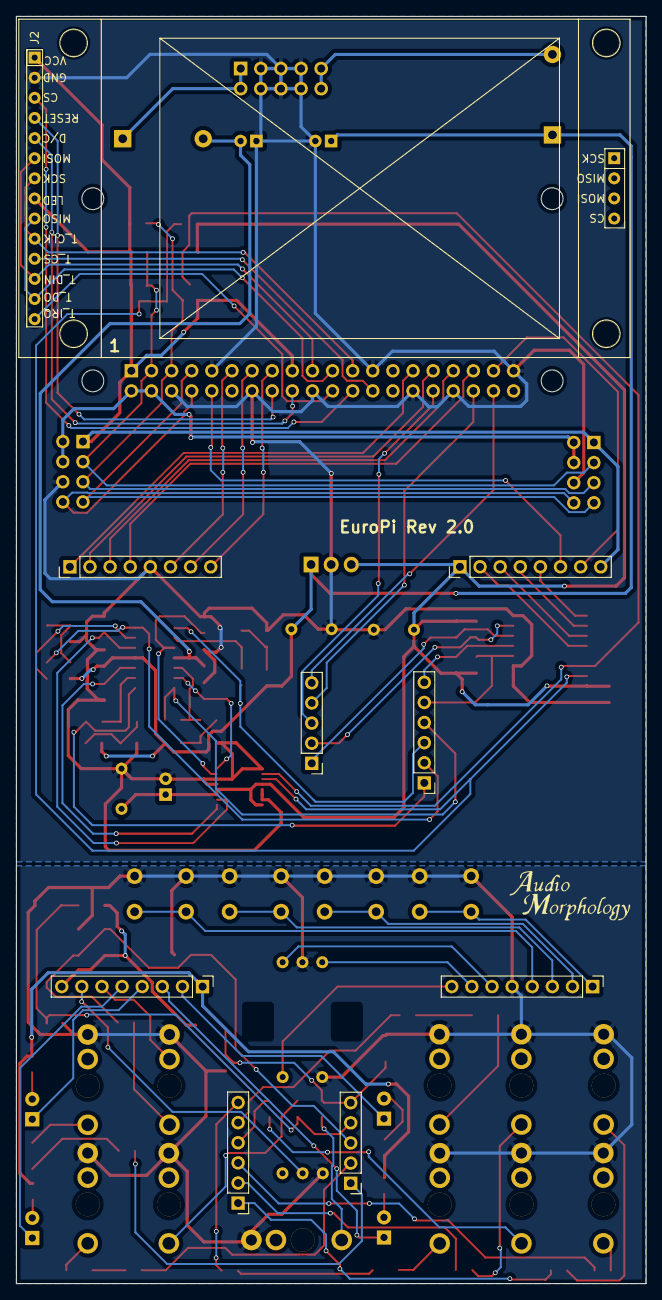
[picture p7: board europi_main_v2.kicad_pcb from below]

Board: 2 copper layers, 79.5 x 160.0 mm, 107 parts (9 on the bottom side), 101 nets.

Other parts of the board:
Eurorack1: CONN_02X05; IDC_Header_Straight_10pins
LM7805: LM7805_TO220; TO-220-3_Vertical
OPA4130: OPA4134; SOIC-14_3.9x8.7mm_P1.27mm

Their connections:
+5V: LM7805.3 (VO); also elsewhere on the board
+12V: LM7805.1 (VI), OPA4130.4 (V+); also elsewhere on the board
-12V: OPA4130.11 (V-); also elsewhere on the board
DACoutA: OPA4130.1; also elsewhere on the board
DACoutB: OPA4130.7; also elsewhere on the board
DACoutC: OPA4130.8; also elsewhere on the board
DACoutD: OPA4130.14; also elsewhere on the board
GND: Eurorack1.3, Eurorack1.4, Eurorack1.5, Eurorack1.6, Eurorack1.7, Eurorack1.8, LM7805.2 (GND); also elsewhere on the board
unnamed 32: Eurorack1.9, Eurorack1.10; also elsewhere on the board
unnamed 33: Eurorack1.1, Eurorack1.2; also elsewhere on the board
unnamed 69: OPA4130.2 (-); also elsewhere on the board
unnamed 70: OPA4130.6 (-); also elsewhere on the board
unnamed 71: OPA4130.9 (-); also elsewhere on the board
unnamed 72: OPA4130.12 (+); also elsewhere on the board
VoutA: OPA4130.3 (+); also elsewhere on the board
VoutB: OPA4130.5 (+); also elsewhere on the board
VoutC: OPA4130.10 (+); also elsewhere on the board
VoutD: OPA4130.13 (-); also elsewhere on the board

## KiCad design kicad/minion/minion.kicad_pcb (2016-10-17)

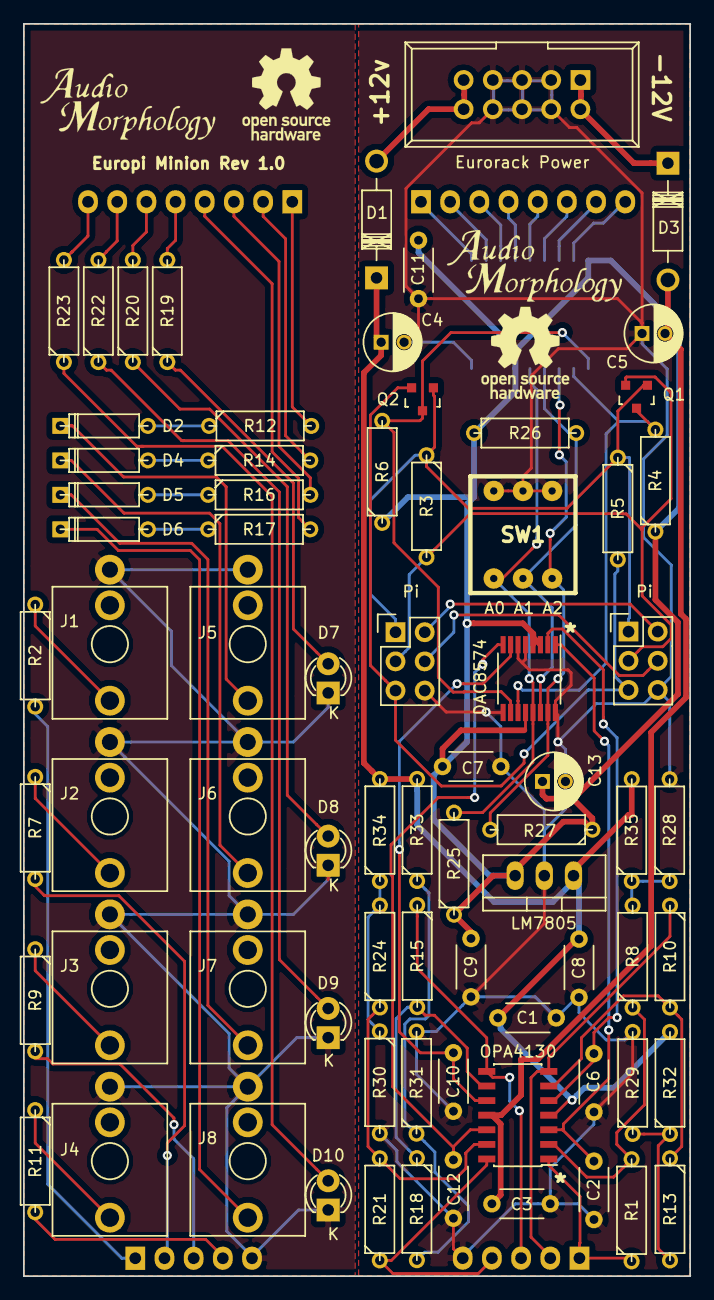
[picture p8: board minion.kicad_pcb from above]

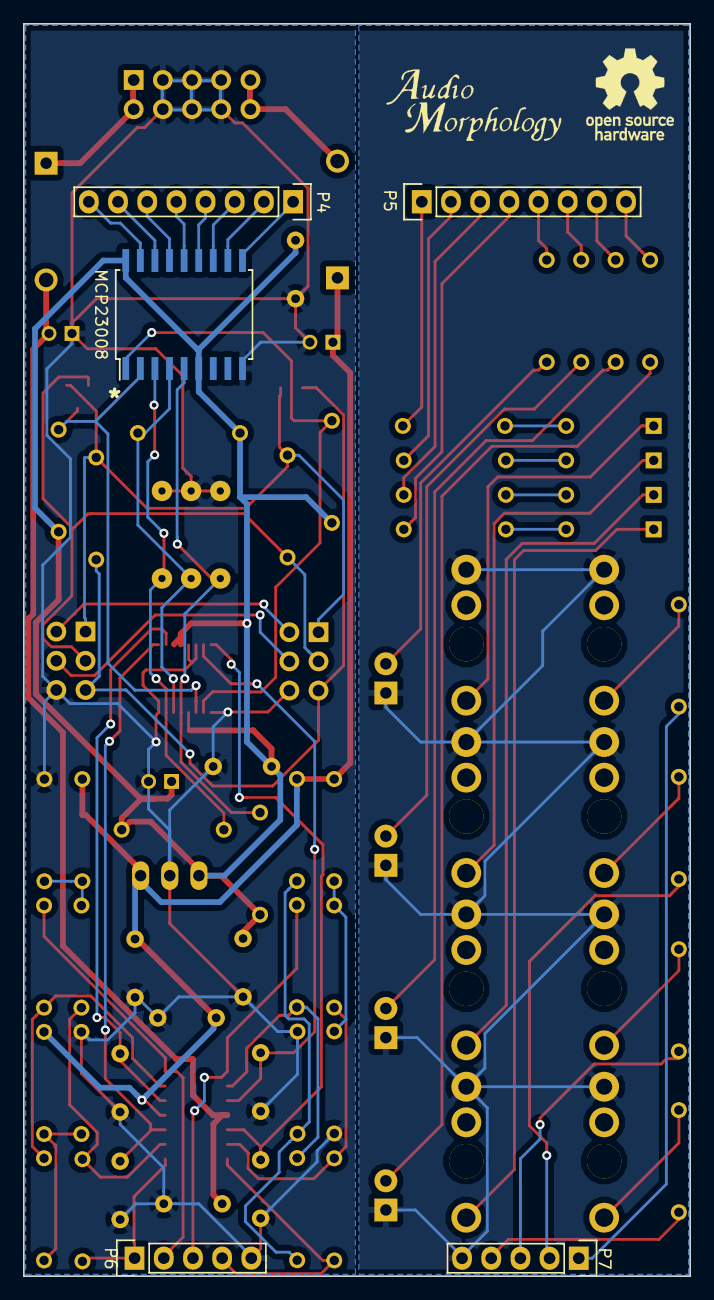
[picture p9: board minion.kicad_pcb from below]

Board: 2 copper layers, 58.0 x 109.0 mm, 80 parts (5 on the bottom side), 68 nets.

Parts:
C1, C2, C3, C6, C10, C11, C12: 10n; tantalum_capacitor
C4, C5, C13: 10uF; C_Radial_D5_L11_P2
C7, C9: 100n; tantalum_capacitor
C8: 330n; tantalum_capacitor
D1, D3: 1N5817; Diode_DO-41_SOD81_Horizontal_RM10
D2, D4, D5, D6: 1N4148; D3
D7, D8, D9, D10: LED; LED-3MM
DAC8574: DAC8574; TSSOP-16_4.4x5mm_Pitch0.65mm
Eurorack Power: CONN_02X05; IDC_Header_Straight_10pins
J1, J2, J3, J4, J5, J6, J7, J8: Thonkiconn
LM7805: RRG7805; 7805
MCP23008: MCP23008; SOIC-18_7.5x11.6mm_Pitch1.27mm
OPA4130: OPA4130; SOIC-14_3.9x8.7mm_Pitch1.27mm
P4, P5: CONN_01X08; Pin_Header_Straight_1x08
P6, P7: CONN_01X05; Pin_Header_Straight_1x05
Pi: CONN_02X03; Pin_Header_Straight_2x03
Pi#2: CONN_02X03; Pin_Header_Straight_2x03
Q1, Q2: BSS138; SOT-23
R1, R10, R15, R21: 2k2; R3-5
R2, R7, R9, R11, R19, R20, R22, R23: 220R; R3-5
R3, R4, R5, R6, R8, R13, R18, R24, R25, R26, R27: 10k; R3-5
R12, R14, R16, R17: 470R; R3-5
R28, R29, R30, R31: 1k; R3-5
R32, R33, R34, R35: 200k; R3-5
SW1: DIPS_03; DIPS-DS03

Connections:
+3V3: Pi.1, Pi#2.1, Q1.1, Q2.1, R3.1, R5.1
+5V: C7.1, C9.1, C11.2, C13.1, DAC8574.3, DAC8574.4, DAC8574.12, LM7805.3, MCP23008.6, MCP23008.18, R4.1, R6.1, R25.1, R26.1, R27.1
+12V: C1.2, C4.1, C8.1, D1.1, LM7805.1, OPA4130.4, R32.2, R33.2, R34.2, R35.2
-12V: C3.2, C5.2, D3.2, OPA4130.11
A0: DAC8574.13, MCP23008.5, R25.2, SW1.1
A1: DAC8574.14, MCP23008.4, R26.2, SW1.2
A2: DAC8574.15, MCP23008.3, R27.2, SW1.3
DACin1: P7.1, R2.2
DACin2: P7.2, R7.2
DACin3: P7.3, R9.2
DACin4: P7.4, R11.2
DACout1: OPA4130.1, P6.1, R1.1
DACout2: OPA4130.7, P6.2, R10.1
DACout3: OPA4130.8, P6.3, R15.1
DACout4: OPA4130.14, P6.4, R21.1
GND: C1.1, C2.2, C3.1, C4.2, C5.1, C6.2, C7.2, C8.2, C9.2, C10.2, C11.1, C12.2, C13.2, D7.1, D8.1, D9.1, D10.1, DAC8574.5, DAC8574.6, DAC8574.9, DAC8574.16, Eurorack Power.3, Eurorack Power.4, Eurorack Power.5, Eurorack Power.6, Eurorack Power.7, Eurorack Power.8, J1.1, J2.1, J3.1, J4.1, J5.1, J6.1, J7.1, J8.1, LM7805.2, MCP23008.9, P6.5, P7.5, Pi.6, Pi#2.6, R28.2, R29.2, R30.2, R31.2, SW1.4, SW1.5, SW1.6
GPin1: P5.1, R12.2
GPin2: P5.2, R14.2
GPin3: P5.3, R16.2
GPin4: P5.4, R17.2
GPin5: P5.5, R19.2
GPin6: P5.6, R20.2
GPin7: P5.7, R22.2
GPin8: P5.8, R23.2
GPout1: MCP23008.10, P4.1
GPout2: MCP23008.11, P4.2
GPout3: MCP23008.12, P4.3
GPout4: MCP23008.13, P4.4
GPout5: MCP23008.14, P4.5
GPout6: MCP23008.15, P4.6
GPout7: MCP23008.16, P4.7
GPout8: MCP23008.17, P4.8
unnamed: D1.2, Eurorack Power.9, Eurorack Power.10
unnamed: D2.1, J5.3
unnamed: D2.2, R12.1
unnamed: D3.1, Eurorack Power.1, Eurorack Power.2
unnamed: D4.1, J6.3
unnamed: D4.2, R14.1
unnamed: D5.1, J7.3
unnamed: D5.2, R16.1
unnamed: D6.1, J8.3
unnamed: D6.2, R17.1
unnamed: D7.2, R19.1
unnamed: D8.2, R20.1
unnamed: D9.2, R22.1
unnamed: D10.2, R23.1
unnamed: J1.3, R2.1
unnamed: J2.3, R7.1
unnamed: J3.3, R9.1
unnamed: J4.3, R11.1
unnamed: Pi.2, Pi#2.2
unnamed: Pi.4, Pi#2.4
unnamed: OPA4130.2, R1.2, R8.1
unnamed: OPA4130.6, R10.2, R13.1
unnamed: R13.2, R29.1, R32.1
unnamed: OPA4130.9, R15.2, R18.1
unnamed: R18.2, R31.1, R33.1
unnamed: OPA4130.13, R21.2, R24.1
unnamed: R24.2, R30.1, R34.1
unnamed: R8.2, R28.1, R35.1
SCL_HV: DAC8574.10, MCP23008.1, Q2.3, R6.2
SCL_LV: Pi.5, Pi#2.5, Q2.2, R5.2
SDA_HV: DAC8574.11, MCP23008.2, Q1.3, R4.2
SDA_LV: Pi.3, Pi#2.3, Q1.2, R3.2
VoutA: C2.1, DAC8574.1, OPA4130.3
VoutB: C6.1, DAC8574.2, OPA4130.5
VoutC: C10.1, DAC8574.7, OPA4130.10
VoutD: C12.1, DAC8574.8, OPA4130.12

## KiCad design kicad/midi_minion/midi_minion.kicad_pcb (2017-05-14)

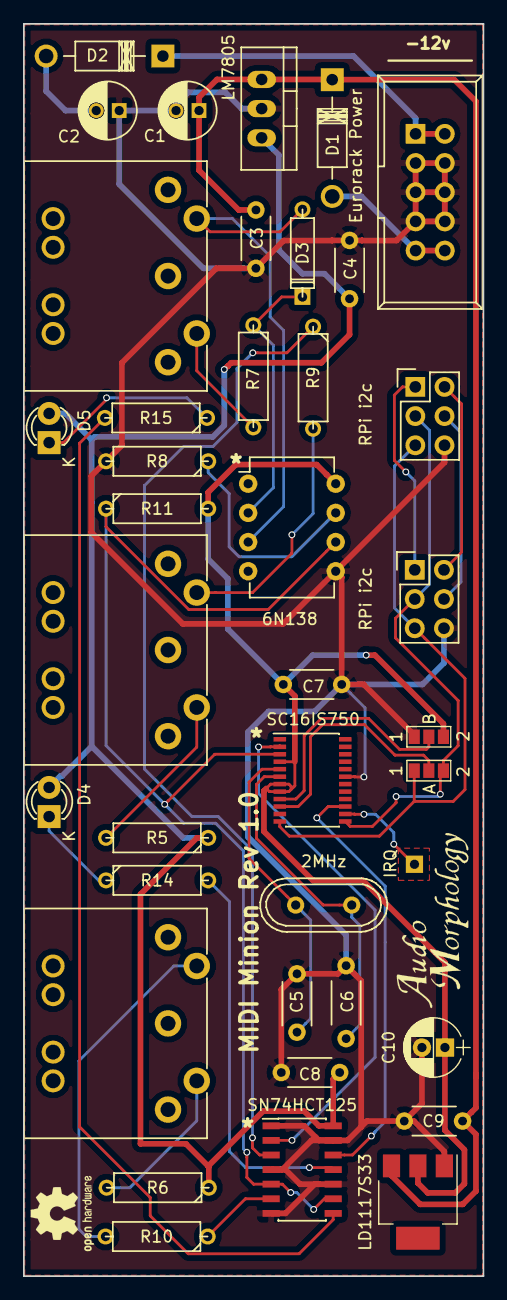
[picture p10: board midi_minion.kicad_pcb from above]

Board: 2 copper layers, 40.0 x 109.0 mm, 37 parts (0 on the bottom side), 32 nets.

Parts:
2MHz: 2MHz; Crystal_HC49-U_Vertical
6N138: 6N138; DIP-8_W7.62mm
C1, C2: 10uF; C_Radial_D5_L11_P2
C3: 330n; tantalum_capacitor
C4, C9: 100n; tantalum_capacitor
C5: 22pF; tantalum_capacitor
C6: 33pF; disc_capacitor
C7, C8: 100nF; tantalum_capacitor
C10: 10uF; CP_Radial_D5.0mm_P2.00mm
D1, D2: 1N5817; Diode_DO-41_SOD81_Horizontal_RM10
D3: 1N4148; D3
D4, D5: LED; LED-3MM
Eurorack Power: CONN_02X05; IDC_Header_Straight_10pins
IRQ: IRQ; Measurement_Point_Square-TH_Small
LD1117S33: LD1117S33TR; SOT-223
LM7805: RRG7805; 7805
P1: MIDI OUT; SDS-50J
P2: MIDI THRU; SDS-50J
P3: MIDI IN; SDS-50J
R5, R6, R7, R9, R10, R15: 220R; R3-5
R8: 1K; R3-5
R11, R14: 470R; R3-5
RPi i2c, RPi i2c#2: CONN_02X03; Pin_Header_Straight_2x03
SC16IS750: SC16IS750; TSSOP-24_4.4x7.8mm_Pitch0.65mm
SN74HCT125: SN74HCT125; SOIC-14_3.9x8.7mm_Pitch1.27mm

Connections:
+3V3: 6N138.8, C7.1, C10.1, LD1117S33.2, R11.2, SC16IS750.4, SC16IS750.7, SC16IS750.8
+5V: C4.1, C8.2, D4.2, D5.2, LM7805.3, R5.1, R6.1, SN74HCT125.14
+12V: C1.1, C3.1, C9.1, D1.1, LD1117S33.3, LM7805.1
-12V: C2.2, D2.2
GND: 6N138.5, C1.2, C2.1, C3.2, C4.2, C5.2, C6.2, C7.2, C8.1, C9.2, C10.2, Eurorack Power.3, Eurorack Power.4, Eurorack Power.5, Eurorack Power.6, Eurorack Power.7, Eurorack Power.8, LD1117S33.1, LM7805.2, R8.2, RPi i2c.6, RPi i2c#2.6, SC16IS750.19, SN74HCT125.1, SN74HCT125.4, SN74HCT125.7, SN74HCT125.10, SN74HCT125.13
unnamed: 2MHz.1, C5.1, SC16IS750.5
unnamed: 2MHz.2, C6.1, SC16IS750.6
unnamed: D1.2, Eurorack Power.9, Eurorack Power.10
unnamed: D2.1, Eurorack Power.1, Eurorack Power.2
unnamed: 6N138.2, D3.1, R7.1
unnamed: 6N138.3, D3.2, P3.5
unnamed: D4.1, R14.1
unnamed: D5.1, R15.1
unnamed: SC16IS750.2, SN74HCT125.2
unnamed: R9.1, SN74HCT125.3
unnamed: 6N138.6, R11.1, SC16IS750.3, SN74HCT125.5, SN74HCT125.9
unnamed: R10.1, SN74HCT125.6
unnamed: R15.2, SN74HCT125.8
unnamed: R14.2, SN74HCT125.11
unnamed: SC16IS750.15, SN74HCT125.12
unnamed: IRQ.1, SC16IS750.14
unnamed: 6N138.7, R8.1
unnamed: P1.4, R5.2
unnamed: P1.5, R9.2
unnamed: P2.4, R6.2
unnamed: P2.5, R10.2
unnamed: P3.4, R7.2
unnamed: RPi i2c.1, RPi i2c#2.1
unnamed: RPi i2c.2, RPi i2c#2.2
unnamed: RPi i2c.4, RPi i2c#2.4
SCL_LV: RPi i2c.5, RPi i2c#2.5, SC16IS750.12
SDA_LV: RPi i2c.3, RPi i2c#2.3, SC16IS750.13

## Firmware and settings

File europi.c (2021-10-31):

// Copyright 2016 Richard R. Goodwin / Audio Morphology
//
// Author: Richard R. Goodwin (richard.goodwin@morphology.co.uk)
//
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
// See http://creativecommons.org/licenses/MIT/ for more information.
 
#include <unistd.h>
#include <stdio.h>
#include <stdlib.h>
#include <string.h>
#include <math.h>
#include <linux/kd.h>
#include <fcntl.h>
#include <linux/fb.h>
#include <sys/mman.h>
#include <pigpio.h>

#include "europi.h"
//#include "quantizer_scales.h"
//#include "../raylib/release/libs/rpi/raylib.h"
#include "../raylib/src/raylib.h"
unsigned hw_version;			/* Type 1: 2,3 Type 2: 4,5,6 & 15 Type 3: 16 or Greater */
struct fb_var_screeninfo vinfo;
struct fb_fix_screeninfo finfo; 
struct fb_var_screeninfo orig_vinfo; 
char *fbp = 0;   
int fbfd = 0; 
int kbfd = 0;
int is_europi = FALSE;	/* whether we are running on Europi hardware - set to True in hardware_init() */
int print_messages = TRUE; /* controls whether log_msg outputs to std_err or not */
int debug = TRUE;		/* controls whether debug messages are printed to the main screen */
int impersonate_hw = FALSE; /*TRUE;	 Forces the software to bypass hardware checks (useful when testing sw without full hw ) */ 
char input_txt[100];    /* buffer for capturing user input */
char current_filename[100]; /* The File we have Open, which is used in File-Save */
char modal_dialog_txt1[50]; /* 1st Line of text for display in Modal Dialog box */
char modal_dialog_txt2[50]; /* 2nd Line of text for display in Modal Dialog box */
char modal_dialog_txt3[50]; /* 2nd Line of text for display in Modal Dialog box */
char modal_dialog_txt4[50]; /* 2nd Line of text for display in Modal Dialog box */
int prog_running=0;		/* Setting this to 0 will force the prog to quit*/
int ThreadEnd = FALSE; /* semaphore to shut down autonomous threads when the prog ends */
int run_stop=STOP;		/* 0=Stop 1=Run: Halts the main step generator */
int save_run_stop;      /* somewhere to store the stop/run state */
int midi_clock_counter = 0; /* divides down the MIDI Clock into pulses per step */
int midi_clock_divisor = 24; /* MIDI Clock pulses per step */
int clock_counter = 95;	/* Main clock counter, tracks the 96 pulses per step */
int clock_level = 0;	/* Master clock phase */
int clock_freq=192;		/* speed of the main internal clock in Hz */
int TuningOn = FALSE;    //FALSE;   /* when True, all CV ports will output the same Raw voltage */
uint16_t TuningVoltage = 0;   /* raw value that is output when Tuning flag is Set */
uint8_t PCF8574_state=0xF0; /* current state of the PCF8574 Ports on the Europi */
int led_on = 0;
int last_track;         /* used to trim the for() loops when looping round all tracks */
int step_one = TRUE;	/* used for resetting the sequence to start from the first step */
int step_one_state = LOW; /*records whether the Step 1 pulse needs to be turned off */
int selected_step = -1;	/* records the step that is currently selected. -1=Nothing selected */
int edit_track = 1;     /* Track being edited */
int edit_step = 1;      /* step being edited */
int SingleChannelOffset = 0; /* first step displayed in Single Channel View */
uint32_t step_tick = 0;	/* used to record the start point of each step in ticks */
uint32_t step_ticks = 250000;	/* Records the length of each step in ticks (used to limit slew length) Init value of 250000 is so it doesn't go nuts */
uint32_t slew_interval = 1000; /* number of microseconds between each sucessive level change during a slew */
/* global variables used by the touchscreen interface */
Vector2 touchPosition = { 0, 0 };
int currentGesture;
int lastGesture;

int  xres,yres,x;
int Xsamples[20];
int Ysamples[20];
int screenXmax, screenXmin;
int screenYmax, screenYmin;
float scaleXvalue, scaleYvalue;
int rawX, rawY, rawPressure, scaledX, scaledY;
int Xaverage = 0;
int Yaverage = 0;
int VerticalScrollPercent = 0;          // How far down the vertical scroll bar the handle is
int sample = 0;
int touched = 0;
int encoder_level_A;
int encoder_level_B;
int encoder_lastGpio;
int encoder_vel;
int disp_menu = 0;
int touchStream = -1;                   // Touch device file descriptor
int touchReady = FALSE;                 // Flag to know if touchscreen is present
pthread_t touchThreadId;  
pthread_t modThreadId[MAX_TRACKS];		// Thread plaeholders for Modulation Tracks
int modThreadRunning[MAX_TRACKS];		// Tracks which Modulation threads have been launched
pthread_t midiThreadId[4];              // 4 x Threads for potential MIDI Listeners 
int midiThreadLaunched[4];             // flags to show whether the listener has launched or not              

enum encoder_focus_t encoder_focus;
enum btnA_func_t btnA_func;
enum btnB_func_t btnB_func;
enum btnC_func_t btnC_func;
enum btnD_func_t btnD_func;
int btnA_state = 0;
int btnB_state = 0;
int btnC_state = 0;
int btnD_state = 0;
uint32_t encoder_tick;
pthread_attr_t detached_attr;		/* Single detached thread attribute used by any /all detached threads */
pthread_mutex_t mcp23008_lock;
pthread_mutex_t pcf8574_lock;
uint8_t mcp23008_state[16];
char **files;                       // Filled with a list of filenames in a directory by file_list( )
size_t file_count;                      
int file_selected;
int first_file;
char *kbfds = "/dev/tty";
char *kbd_chars[4][11] = {{"1","2","3","4","5","6","7","8","9","0","_"},
                        {"/","q","w","e","r","t","y","u","i","o","p"},
                        {"/","a","s","d","f","g","h","j","k","l","."},
                        {" "," ","z","x","c","v","b","n","m","~","]"}};		// Note ~ = Backspace, and ] is Return
int kbd_char_selected = 0;
char debug_messages[10][80];
int next_debug_slot = 0;

/* Raylib-related stuff */
Font font1;
Texture2D Splash;	                // Splash screen texture
Texture2D KeyboardTexture;          // Keyboard Overlay texture
Texture2D DialogTexture;            // Common dialog control
Texture2D SmallDialogTexture;       // small floating dialog
Texture2D TextInputTexture;         // text input dialog box
Texture2D Text2chTexture;           // 2 Character text box (used for Channel number, step number etc)
Texture2D Text5chTexture;           // 5 Character text box 
Texture2D Text10chTexture;          // 10 Character text box 
Texture2D TopBarTexture;            // Top (menu) bar texture
Texture2D MainScreenTexture;        // Main screen
Texture2D ButtonBarTexture;         // Soft-button graphic bar
Texture2D VerticalScrollBarTexture; // Vertical scroll bar for RHS of screen
Texture2D VerticalScrollBarShortTexture; // Short Vertical scroll bar for RHS of screen
Texture2D ScrollHandleTexture;      // Scroll handle for Vewrtical Scroll Bar


/* declare and populate the menu structure */ 
menu mnu_file_open = 	{0,0,dir_none,"Open",&file_open,{NULL}};
menu mnu_file_save = 	{0,0,dir_none,"Save",&file_save,{NULL}};
menu mnu_file_saveas = 	{0,0,dir_none,"Save As",&file_saveas,{NULL}};
menu mnu_file_new = 	{0,0,dir_none,"New",&file_new,{NULL}};
menu mnu_file_quit = 	{0,0,dir_none,"Quit",&file_quit,{NULL}};

menu mnu_seq_new = 		{0,0,dir_none,"New",&seq_new,{NULL}};
menu mnu_seq_setslew =  {0,0,dir_none,"Set Slew for Step",&seq_setslew,{NULL}};
menu mnu_seq_setloop =	{0,0,dir_none,"Set Track Length",&seq_setloop,{NULL}};
menu mnu_seq_setpitch = {0,0,dir_none,"Set Pitch for step",&seq_setpitch,{NULL}};
menu mnu_seq_setdir =   {0,0,dir_none,"Set Track Direction",&seq_setdir,{NULL}};
menu mnu_seq_quantise = {0,0,dir_none,"Set Quantization",&seq_quantise,{NULL}};
menu mnu_seq_singlechnl = {0,0,dir_none,"Single Channel View",&seq_singlechnl,{NULL}};
menu mnu_seq_gridview = {0,0,dir_none,"Grid View",&seq_gridview,{NULL}};
menu mnu_seq_grid8x8 = {0,0,dir_none,"8x8 Grid View",&seq_grid8x8,{NULL}};

menu mnu_config_setzero = {0,0,dir_left,"Set Zero",&config_setzero,{NULL}};
menu mnu_config_set10v = {0,0,dir_left,"Set 10 Volt",&config_setten,{NULL}};
menu mnu_config_debug = {0,0,dir_left,"Debug on/off",&config_debug,{NULL}};
menu mnu_config_tune = {0,0,dir_left,"Tuning on/off",&config_tune,{NULL}};

menu mnu_test_scalevalue = {0,0,dir_left,"Test scale value",&test_scalevalue,{NULL}};
menu mnu_test_keyboard = {0,0,dir_left,"Test Keyboard",&test_keyboard,{NULL}};

menu mnu_play_step_one = {0,0,dir_left,"Step One",&set_step_one,{NULL}};

menu sub_end = {0,0,dir_none,NULL,NULL,{NULL}}; //set of NULLs to mark the end of a sub menu

menu Menu[]={
	{0,1,dir_down,"File",NULL,{&mnu_file_open,&mnu_file_save,&mnu_file_saveas,&mnu_file_new,&mnu_file_quit,&sub_end}},
	{0,0,dir_down,"Sequence",NULL,{&mnu_seq_setslew,&mnu_seq_setloop,&mnu_seq_setpitch,&mnu_seq_setdir,&mnu_seq_grid8x8,&mnu_seq_gridview,&mnu_seq_singlechnl,&mnu_seq_new,&sub_end}},
//	{0,0,dir_down,"Sequence",NULL,{&mnu_seq_setslew,&mnu_seq_setloop,&mnu_seq_setpitch,&mnu_seq_setdir,&mnu_seq_quantise,&mnu_seq_gridview,&mnu_seq_singlechnl,&mnu_seq_new,&sub_end}},
	{0,0,dir_down,"Conf",NULL,{&mnu_config_setzero,&mnu_config_set10v,&mnu_config_debug,&mnu_config_tune,&sub_end}},
	{0,0,dir_down,"Test",NULL,{&mnu_test_scalevalue,&mnu_config_setzero,&mnu_test_keyboard,&sub_end}},
	{0,0,dir_down,"Play",NULL,{&mnu_play_step_one,&sub_end}},
	{0,0,dir_down,NULL,NULL,{NULL}}
	};


/* This is the main structure that holds info about the running sequence */
struct europi Europi; 
struct europi_hw Europi_hw;
enum display_page_t DisplayPage = GridView;
uint32_t ActiveOverlays;

#define MAX_GESTURE_STRINGS   20

// application entry point 
int main(int argc, char* argv[])
{
	unsigned int iseed = (unsigned int)time(NULL);
	srand (iseed);
	/* things to do when prog first starts */
	startup();
	/* Read and set the states of the run/stop and int/ext switches */
	log_msg("Run/stop: %d\n",gpioRead(RUNSTOP_IN));
	run_stop = !gpioRead(RUNSTOP_IN);
	// If we're impersonating HW then may
	// as well set it to run with an Internal Clock
	if(impersonate_hw == TRUE){
		run_stop = RUN; //STOP; 
	}
    //debug = TRUE;
    currentGesture = GESTURE_NONE;
    lastGesture = GESTURE_NONE;
    //SetGesturesEnabled(0b0000000011100011);   //None, tap & DoubleTap 

    SetTargetFPS(60);		// Seems this is necessary, or GESTURE_TAP & SWIPE aren't detected!!
 
while (!WindowShouldClose() && (prog_running ==1)) {
	
    lastGesture = currentGesture;
    currentGesture = GetGestureDetected();
    touchPosition = GetTouchPosition(0);
/*
	if (currentGesture != lastGesture)
		{

		  switch (currentGesture)
			{
				case GESTURE_TAP: log_msg("GESTURE TAP"); break;
				case GESTURE_DOUBLETAP: log_msg( "GESTURE DOUBLETAP"); break;
				case GESTURE_HOLD: log_msg("GESTURE HOLD"); break;
				case GESTURE_DRAG: log_msg("GESTURE DRAG"); break;
				case GESTURE_SWIPE_RIGHT: log_msg("GESTURE SWIPE RIGHT"); break;
				case GESTURE_SWIPE_LEFT: log_msg("GESTURE SWIPE LEFT"); break;
				case GESTURE_SWIPE_UP: log_msg("GESTURE SWIPE UP"); break;
				case GESTURE_SWIPE_DOWN: log_msg("GESTURE SWIPE DOWN"); break;
				case GESTURE_PINCH_IN: log_msg("GESTURE PINCH IN"); break;
				case GESTURE_PINCH_OUT: log_msg("GESTURE PINCH OUT"); break;
				default: break;
			}
		}
*/
    switch(DisplayPage){
        case GridView:
			gui_grid();
        break;
		case Grid8x8:
			gui_8x8();
		break;
        case SingleStep:
            gui_singlestep();
        break;
        case SingleChannel:
            gui_SingleChannel();
        break;
        case SingleAD:
            gui_SingleAD();
        break;
        case SingleADSR:
            gui_SingleADSR();
        break;
    }
 
    usleep(100); 
}
    ThreadEnd = TRUE;
    // Wait for various joinable threads to end
	pthread_join(touchThreadId, NULL);
    int i;
    for(i=0;i<MAX_TRACKS;i++) {
        if(modThreadRunning[i] == TRUE) pthread_join(modThreadId[i], NULL);
    }
    for(i=0;i<4;i++) {
        if(midiThreadLaunched[i] == TRUE) pthread_join(midiThreadId[i], NULL);
    }
	shutdown();
	sleep(2);
	return 0;
  
}

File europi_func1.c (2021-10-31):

// Copyright 2016 Richard R. Goodwin / Audio Morphology
//
// Author: Richard R. Goodwin (richard.goodwin@morphology.co.uk)
//
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
// See http://creativecommons.org/licenses/MIT/ for more information.

//#include <linux/input.h>
#include <unistd.h>
#include <stdio.h>
#include <stdarg.h>
#include <stdlib.h>
#include <string.h>
#include <fcntl.h>
#include <linux/fb.h>
#include <sys/mman.h>
#include <sys/ioctl.h>
#include <linux/kd.h>
#include <pigpio.h>
#include <signal.h>

#include "europi.h"
//#include "front_panel.c"
//#include "touch.h"
//#include "touch.c"
//#include "quantizer_scales.h"
#include "../raylib/src/raylib.h"

//extern struct europi;
extern struct fb_var_screeninfo vinfo;
extern struct fb_fix_screeninfo finfo;
extern struct fb_var_screeninfo orig_vinfo;

extern unsigned hw_version; 
extern int fbfd;
extern char *fbp;
extern char *kbfds;
extern int impersonate_hw;
extern int debug; 
extern char debug_messages[10][80];
extern char modal_dialog_txt1[];
extern char modal_dialog_txt2[];
extern char modal_dialog_txt3[];
extern char modal_dialog_txt4[];
extern int next_debug_slot;
extern char input_txt[];  
extern int kbfd;
extern int ThreadEnd;
extern int prog_running;
extern int run_stop; 
extern int save_run_stop;
extern int is_europi; 
extern int midi_clock_counter;
extern int midi_clock_divisor;
extern int retrig_counter;
extern int extclk_counter;
extern int extclk_level;
extern int clock_counter;
extern int clock_level;
extern int clock_freq;
extern int clock_source;
extern int TuningOn;
extern uint16_t TuningVoltage; 
extern uint8_t PCF8574_state;
extern int led_on;
extern int print_messages;
//extern unsigned int sequence[6][32][3];
//extern int current_step;
//extern int last_step;
extern int last_track;
extern int selected_step;
extern int step_one;
extern int step_one_state;
extern uint32_t step_tick;
extern uint32_t step_ticks;
extern uint32_t slew_interval;
/* globals used by touchscreen interface */
extern int  xres,yres,x;
extern int Xsamples[20];
extern int Ysamples[20];
extern int screenXmax, screenXmin;
extern int screenYmax, screenYmin;
extern float scaleXvalue, scaleYvalue;
extern int rawX, rawY, rawPressure, scaledX, scaledY;
extern int Xaverage;
extern int Yaverage;
extern int VerticalScrollPercent;
extern int sample;
extern int touched;
extern int encoder_level_A;
extern int encoder_level_B;
extern int encoder_lastGpio;
extern int encoder_pos;
extern int encoder_vel;
extern uint32_t encoder_tick;
extern enum encoder_focus_t encoder_focus;
extern enum btnA_func_t btnA_func;
extern enum btnB_func_t btnB_func;
extern enum btnC_func_t btnC_func;
extern enum btnD_func_t btnD_func;
extern int btnA_state;
extern int btnB_state;
extern int btnC_state;
extern int btnD_state;
extern struct europi Europi;
extern struct europi_hw Europi_hw;
extern enum display_page_t DisplayPage;
//extern struct screen_overlays ScreenOverlays;
extern uint32_t ActiveOverlays;
extern int kbd_char_selected;
extern struct MENU Menu[];
extern pthread_attr_t detached_attr;		
extern pthread_mutex_t mcp23008_lock;
extern pthread_mutex_t pcf8574_lock;
extern pthread_t midiThreadId[]; 
extern int midiThreadLaunched[];
extern uint8_t mcp23008_state[16];
extern int test_v;
pthread_t ThreadId; 		// Pointer to detatched Thread Ids (re-used by each/every detatched thread)
extern Font font1;
extern Texture2D Splash;
extern Texture2D KeyboardTexture;
extern Texture2D DialogTexture;
extern Texture2D SmallDialogTexture;
extern Texture2D TextInputTexture;
extern Texture2D Text2chTexture;
extern Texture2D Text5chTexture;
extern Texture2D Text10chTexture;
extern Texture2D MainScreenTexture;
extern Texture2D TopBarTexture;
extern Texture2D ButtonBarTexture; 
extern Texture2D VerticalScrollBarTexture;
extern Texture2D VerticalScrollBarShortTexture;
extern Texture2D ScrollHandleTexture;
extern int disp_menu;	
extern char **files;
extern char *kbd_chars[4][11];
extern size_t file_count;                      
extern int file_selected;
extern int first_file;


/* Internal Clock
 * 
 * This is the main timing loop for the 
 * whole programme, and which runs continuously
 * from program start to end.
 * 
 * The Master Clock runs at 96 * The BPM step
 * frequency
 *
 * This drives PIN 10 (GPIO 15), which loops back 
 * via the Clock In jack 
 */
void master_clock(int gpio, int level, uint32_t tick)
{
	if (run_stop == RUN){
		if (clock_counter++ > 95) {
			clock_counter = 0;
			gpioWrite(INT_CLK_OUT, 1);
		}
		if (clock_counter == 48) gpioWrite(INT_CLK_OUT,0);
	}
}

/* Main Clock - this is the function that advances the 
* sequnce on to the next step. The master clock is normalled
* back into this input via the external clock jack, thus
* inserting a jack into the Clock In input cuts out the
* internal clock and replaces it with the external clock
* signal
 */
void main_clock(int gpio, int level, uint32_t tick)
{
	if (run_stop == RUN){
		// Copy the clock signal to the Clock Out port
		GATESingleOutput(Europi.tracks[0].channels[GATE_OUT].i2c_handle,CLOCK_OUT,DEV_PCF8574,level);
		//GATESingleOutput(1,CLOCK_OUT,DEV_PCF8574,level);
		if (level == 1) next_step();
	}
}

/* run/stop switch input
 * called whenever the switch changes state
 */
void runstop_input(int gpio, int level, uint32_t tick)
{
	run_stop = !level;
}
/* Reset input
 * Rising edge causes next step to be Step 1
 */
void reset_input(int gpio, int level, uint32_t tick)
{
	if (level == 1)	step_one = TRUE;
}
/* Hold input
 * nOT QUITE SURE WHAT TO DO WITHH THIS YET!!
 */
void hold_input(int gpio, int level, uint32_t tick)
{
	if(level == 1){
	}

}
/*
* Manually force Step One to tbe the next step 
*/
void set_step_one(void)
{
	step_one = TRUE;	
}
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

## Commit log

2016-10-17 Added Kicad project, schematic and PCB files for Europi & Minion, including Frontpanels laid out in Kicad
    [europi_main.kicad_pcb, europi_main.sch, europi_main_frontpanel.kicad_pcb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]
2016-10-23 new file: hardware/bom.ods new file: hardware/pi_header_pinout_assignment.ods
    [BOM.ods, bom.ods, pi_header_pinout_assignment.ods]
2016-10-23 removed redundant directory
    [BOM.ods]
2016-10-23 Added project-specific Kicad library
2016-11-10 now launching detached threads for handling gates, Triggers and re-trigging
2016-11-27 added bgr=1 argument to fbtft driver config to swap Red & Blue on SpotPear TFT
    [europi.c, europi_func1.c]
2016-12-06 set zero & set 10v config functions working, basic save & load sequences completed
2016-12-11 quantisation select and step pitch set menu functions
2016-12-18 Prototype single channel view
2017-01-02 Touchscreen mapped to mouse movements via tslib and ts_uinput virtual device
2017-01-11 Updated Pi Header pinouts
    [Pi Header Pinout assignment.ods]
2017-01-31 Added soft-button bar graphic
2017-01-31 Implemented soft-button structure to mimick the physical buttons, so that both behave identically
2017-02-02 moved the set loop, scale and pitch functions into the gui
2017-02-04 set pitch moved to new GUI, debug messages can now be directed to TFT screen overlay
2017-02-05 fixed the pitch adjust so it correctly leaps to the next quantised note value
    [europi.c, europi.h, europi_func1.c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]
2017-03-28 Started adding MIDI Minion BOM items
    [bom.ods]
2017-03-29 MIDI Minion Rev 1.0 Schematic & Brd files
    [midi_minion.kicad_pcb, midi_minion.sch, midi_minion_frontpanel.kicad_pcb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]
2017-06-06 fixed most recent batch of compiler warnings
    [europi.c, europi.h, europi_func1.c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]
2017-06-07 Added Track direction (Fwd, Reverse, Pendulum, Random)
    [europi.c, europi.h, europi_func1.c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]
2017-06-07 bug fix in Pendulum track direction
    [europi_func1.c]
2017-06-07 bug fix in MIDI Out
    [europi.c, europi_func1.c]
2017-06-13 developing pitch editor using bargraph paradigm
2017-06-25 ratchetting gate display on single track page
2017-06-27 hardware config changes saved to disk, Modal Dialog implementation, Set zero and Set 10v implemented
2017-07-06 added global tuning flag to force all CV channels to temporarily output the same Raw voltage (Scaled appropriately)
2017-07-12 tidied up the logged messages in the MinionFinder routines to clarify the i2c addresses that each device is using
2017-12-13 Fixed screen overlay flags
    [europi_func1.c, europi_func2.c, europi_gui.c]
2017-12-18 fixed the gesture tap detection
    [europi.c, europi_gui.c]
2017-12-24 implented short scroll bar for when top menu bar active
    [europi.c, europi.h, europi_func1.c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]
2018-01-15 KiCad footprint & 3D Model s uploaded
2021-01-04 Various GUI bug fixes
    [Pi Header Pinout assignment.ods, bom.ods, europi_main.kicad_pcb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]
2021-01-06 Overlay Timer thread
2021-01-19 Small fix to Slew GUI
    [europi_gui.c]
2021-03-13 Add files via upload
    Europi Version 2 schematic, board and Front Panel
    [europi_main_frontpanel.kicad_pcb, europi_main_v2 BOM.ods, europi_main_v2.kicad_pcb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]
2021-03-13 Add files via upload
    Gerbers for the Europi Main board Version 2
    [europi_main_v2-B_Cu.gbr, europi_main_v2-B_Mask.gbr, europi_main_v2-B_Silkscreen.gbr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]
2021-03-13 Create front panel gerbers
2021-03-13 Add files via upload
    Gerbers for the Europi V2 Front Panel
    [europi_main_frontpanel-Edge_Cuts.gbr, europi_main_frontpanel-F_Cu.gbr, europi_main_frontpanel-F_Mask.gbr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]
2021-03-28 Fixed quant problems on Track 2
    [europi_func1.c, europi_func2.c]
2021-03-28 Starting work on Modulation channel threads
2021-04-11 Modulation Thread creation
2021-04-18 Added per-track clock divisor
